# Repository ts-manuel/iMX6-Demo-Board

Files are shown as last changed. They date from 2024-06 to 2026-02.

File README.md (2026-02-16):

# i.MX6 Demo Board
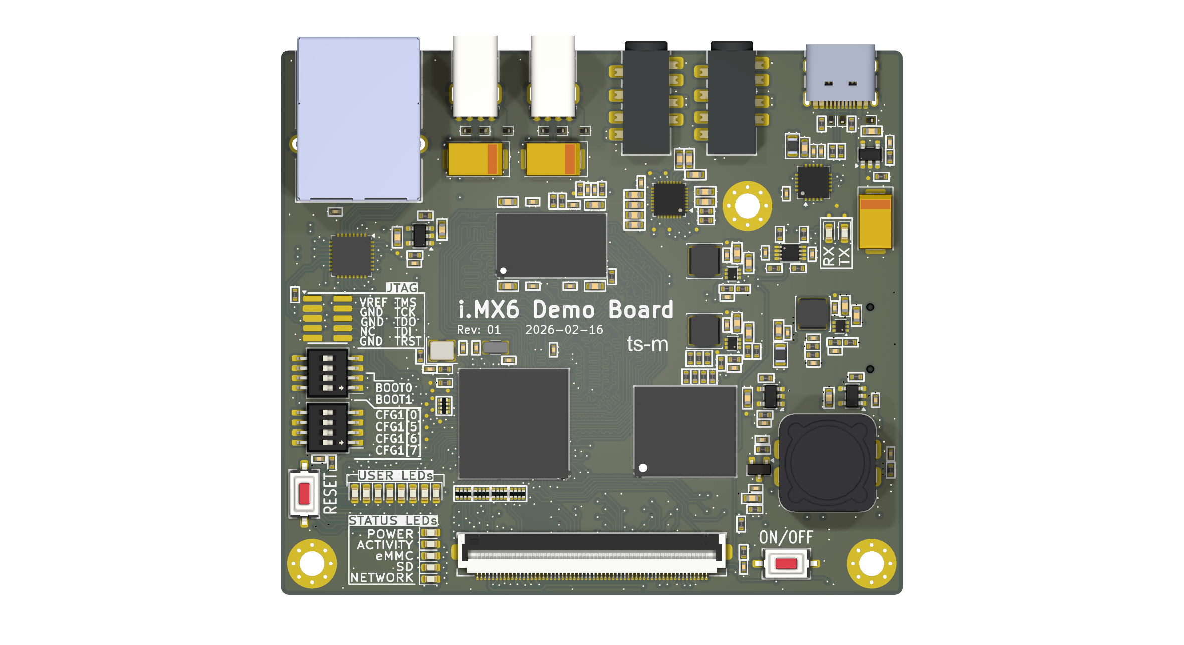
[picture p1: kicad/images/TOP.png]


<!-- TABLE OF CONTENTS -->
<details open="open">
  <summary>Table of Contents</summary>
  <ol>
    <li><a href="#about-the-project">About The Project</a></li>
    <li><a href="#hardware-specifications">Hardware Specifications</a></li>
    <li><a href="#software">Software</a></li>
    <li><a href="#schematic">Schematic</a></li>
  </ol>
</details>

<!-- ABOUT THE PROJECT -->
## About The Project
This repository contains the design files and documentation for a custom-built Linux demo board based on the NXP i.MX6ULL (900 MHz ARM Cortex-A7). The purpose of this project isn't to solve a specific problem or build a commercial product. This is a dedicated learning platform designed to bridge the gap between simple micro-controllers and complex application processors. While micro-controllers (like STM32 or ESP32) are great for real-time tasks, application processors are better suited for "heavy lifting" and high-level software stacks. Checkout the full schematic [schematic](./kicad/schematic/iMX6%20Demo%20Board.pdf) and the <a href="https://htmlpreview.github.io/?https://github.com/ts-manuel/iMX6-Demo-Board/blob/main/kicad/bom/ibom.html" target="_blank">Interactive BOM</a>.

### Hardware Specifications
- **System**
    - CPU: NXP i.MX6ULL @ 900 MHz (ARM Cortex-A7)
    - RAM: 512 MB DDR3
- **Storage:**
    - 4 GB eMMC (On-board)
    - 32 MB NOR Quad SPI
    - Micro SD-Card Slot
- **Connectivity:**
    - 1x 100Mb Ethernet
    - 2x USB 2.0 Host (Type A)
    - 1x USB 2.0 Device (Type C)
    - 2x Audio Jacks 3.5 mm (WM8904 Codec)
- **UI & Indicators:**
    - 24-bit LCD Interface
    - 8x User LEDs + 5x Status LEDs

<!-- SOFTWARE -->
## Software
The current goal is to compile a basic Linux image using the Yocto Project to exercise and validate every hardware feature on the board (Ethernet, USB, Display, and GPIO).

**Status: In Progress**. Development of the custom meta-layer and bitbake recipes is currently underway.

<!-- SCHEMATIC -->
## Schematic
Checkout the full [schematic](./kicad/schematic/iMX6%20Demo%20Board.pdf) in PDF.

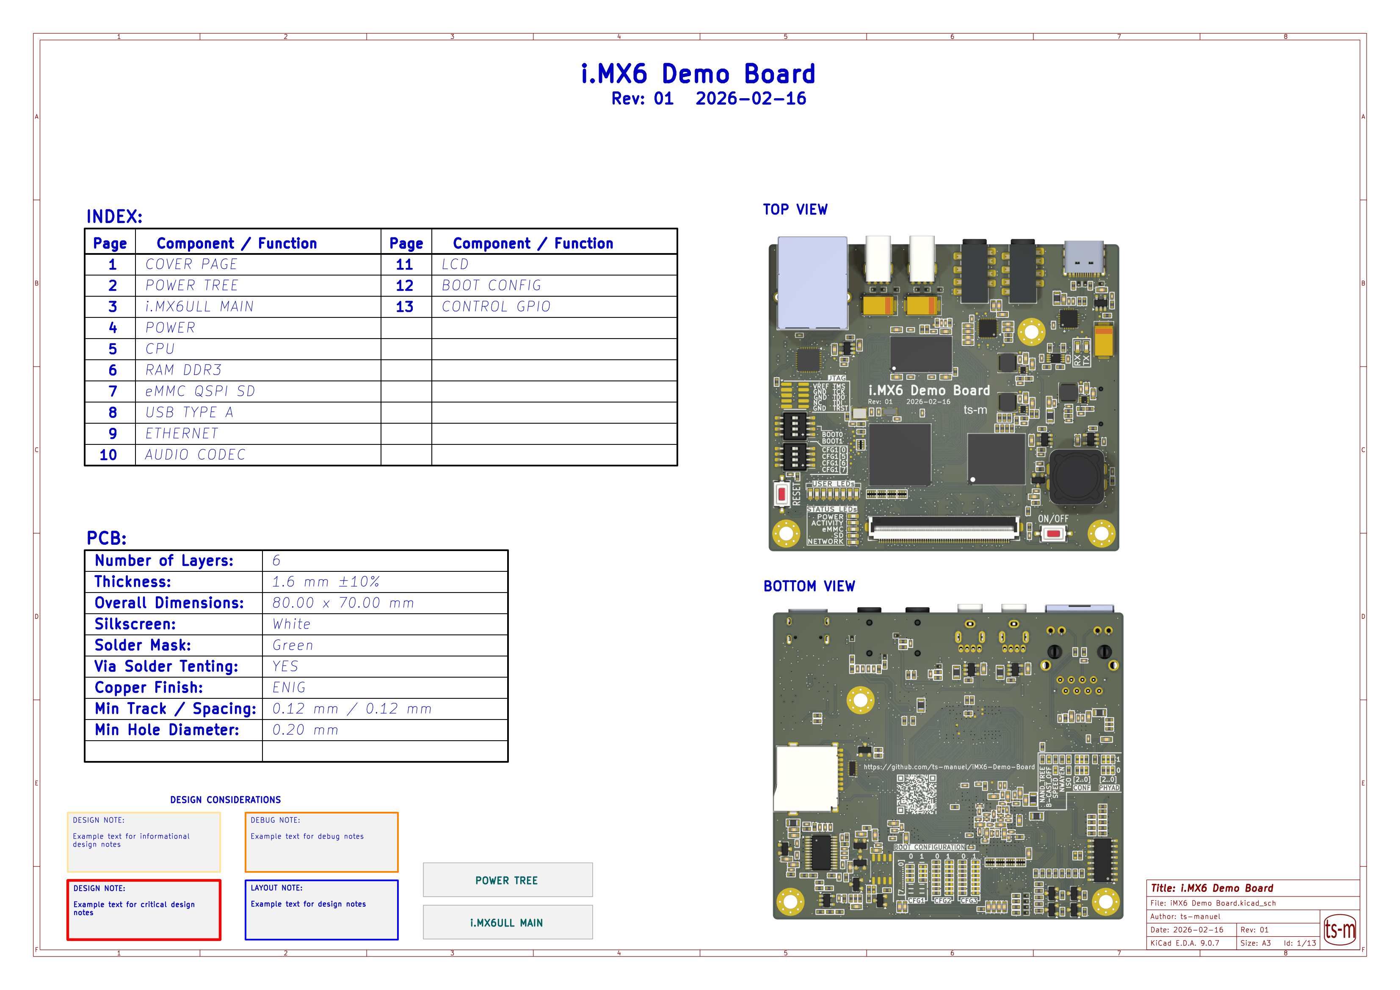
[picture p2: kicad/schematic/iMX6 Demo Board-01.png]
iMX6 Demo Board-01.png


### POWER TREE
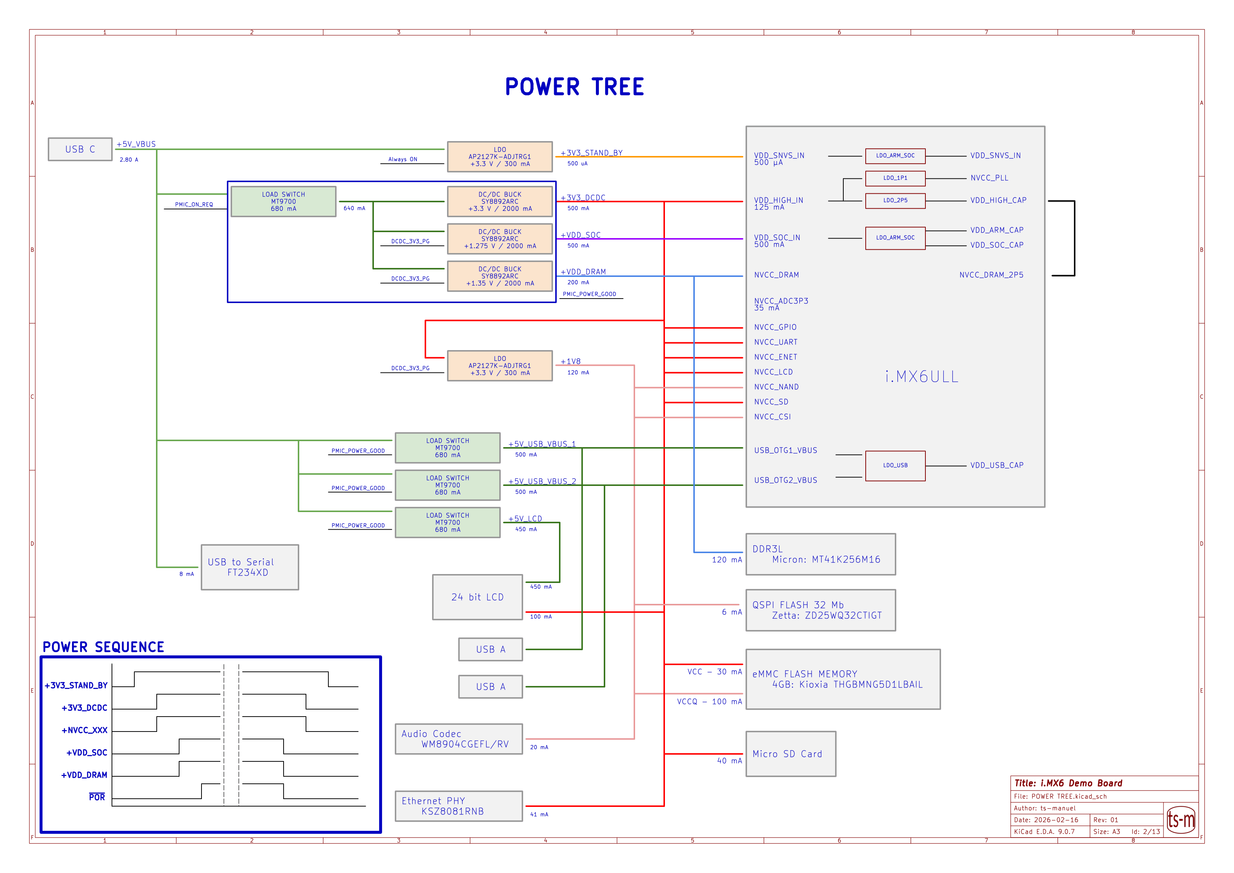
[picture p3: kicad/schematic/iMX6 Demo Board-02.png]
iMX6 Demo Board-02.png


### BLOCK DIAGRAM
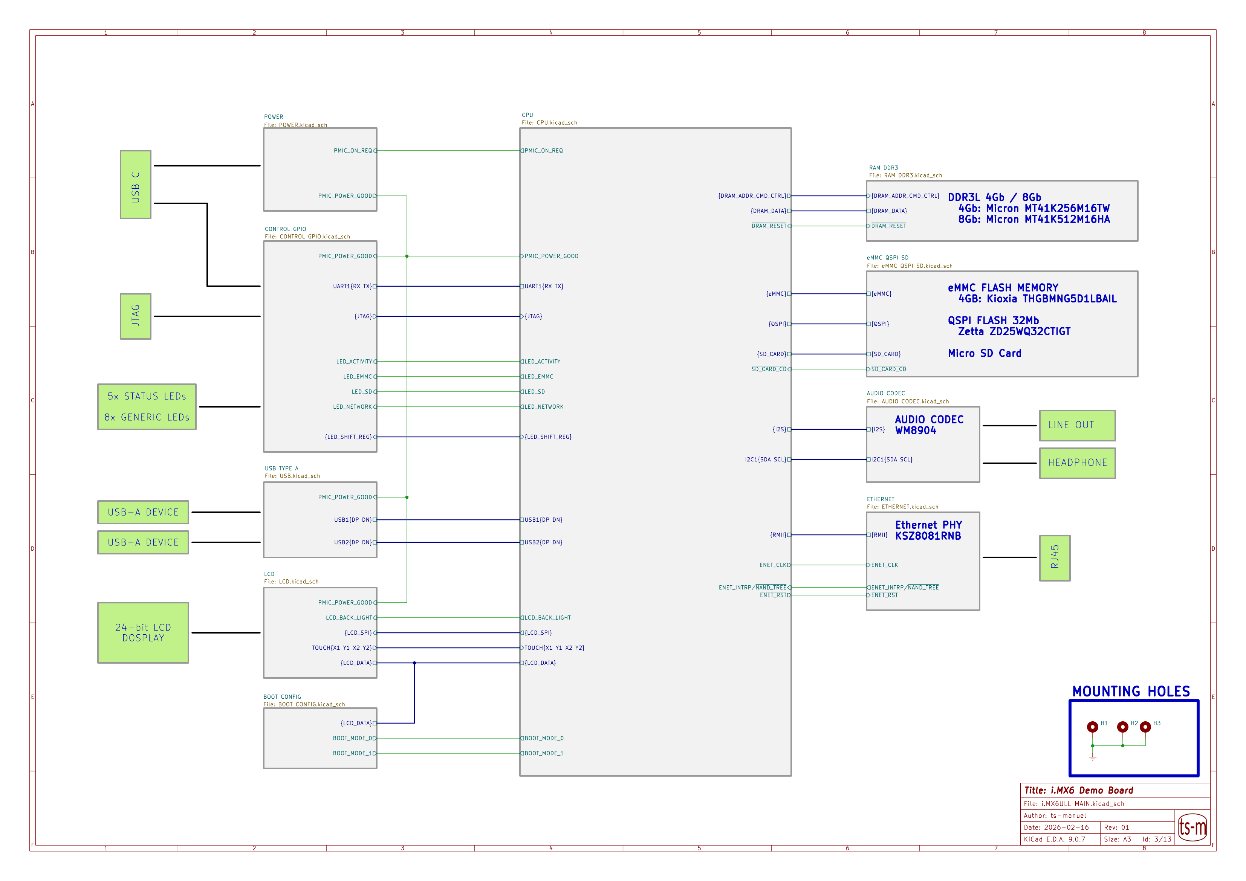
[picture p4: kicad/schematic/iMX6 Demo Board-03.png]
iMX6 Demo Board-03.png


### POWER
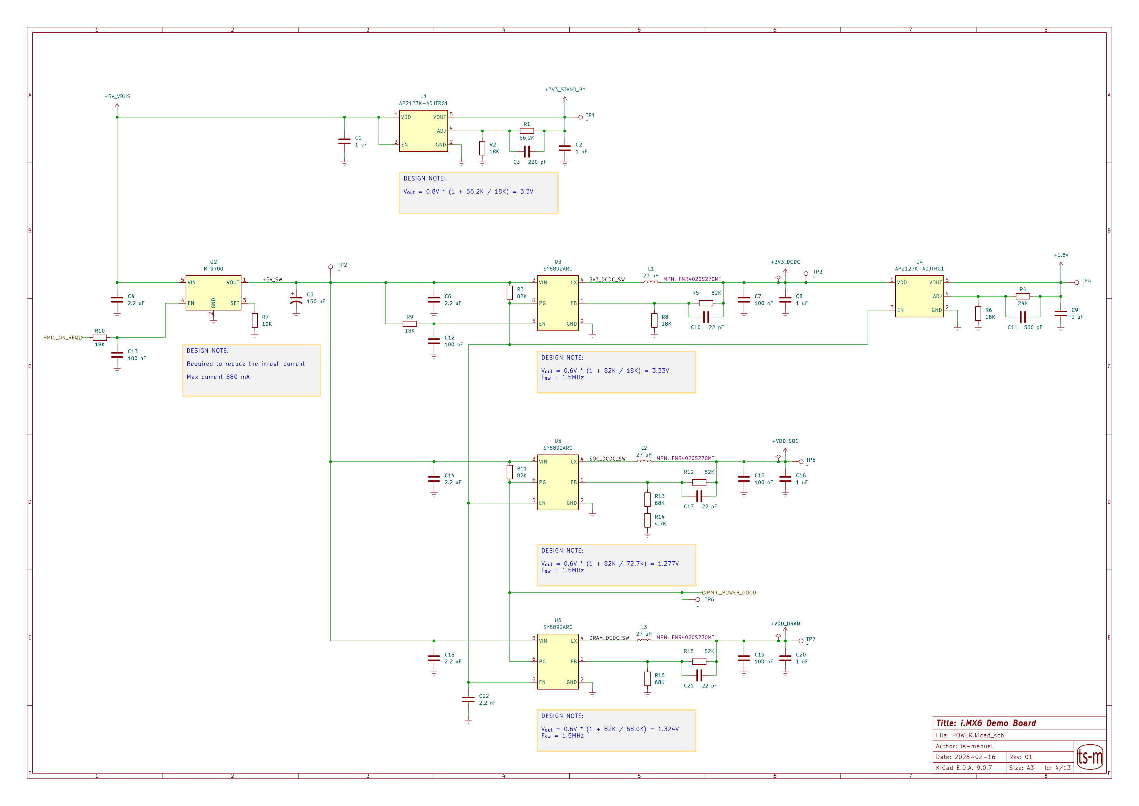
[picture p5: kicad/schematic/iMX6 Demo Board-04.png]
iMX6 Demo Board-04.png


### CPU
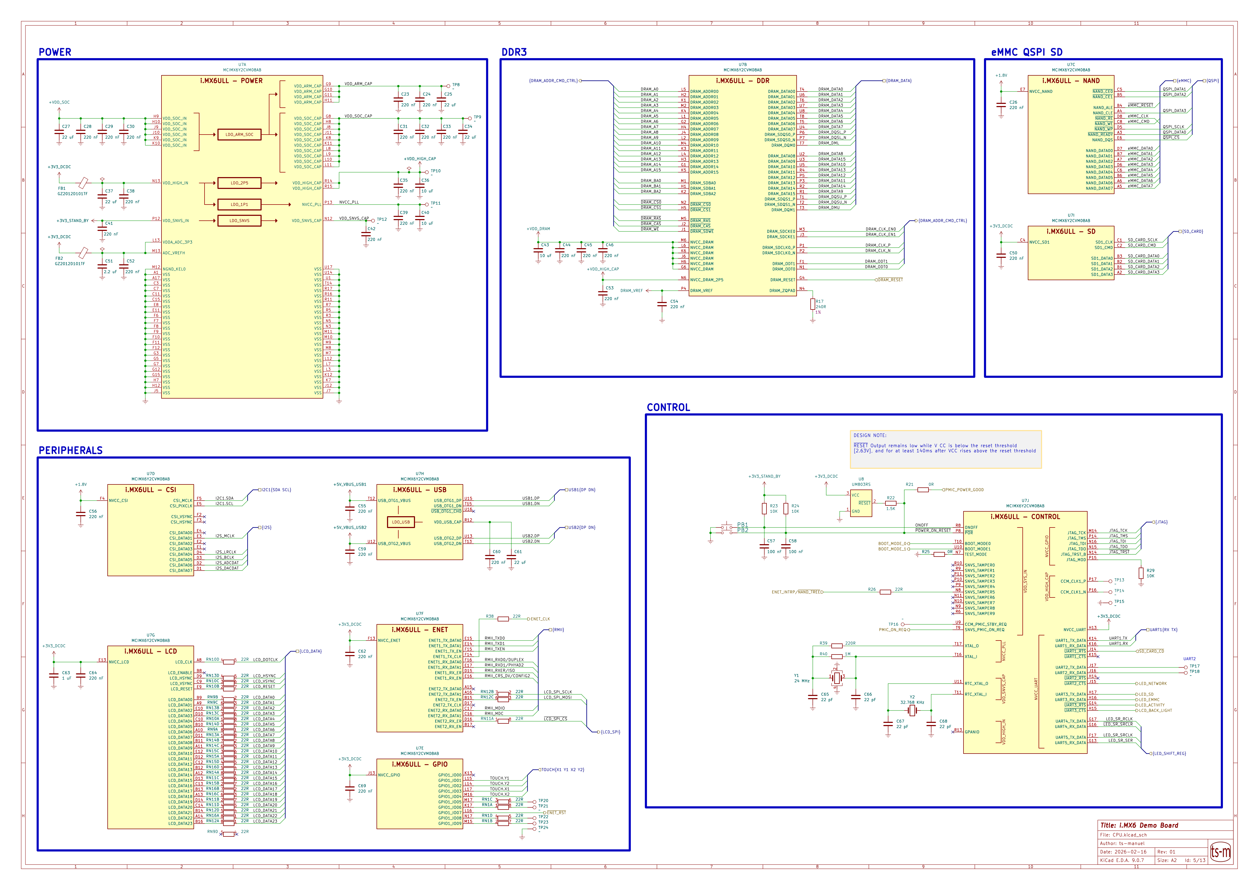
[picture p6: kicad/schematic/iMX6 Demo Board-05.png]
iMX6 Demo Board-05.png


### RAM DDR3
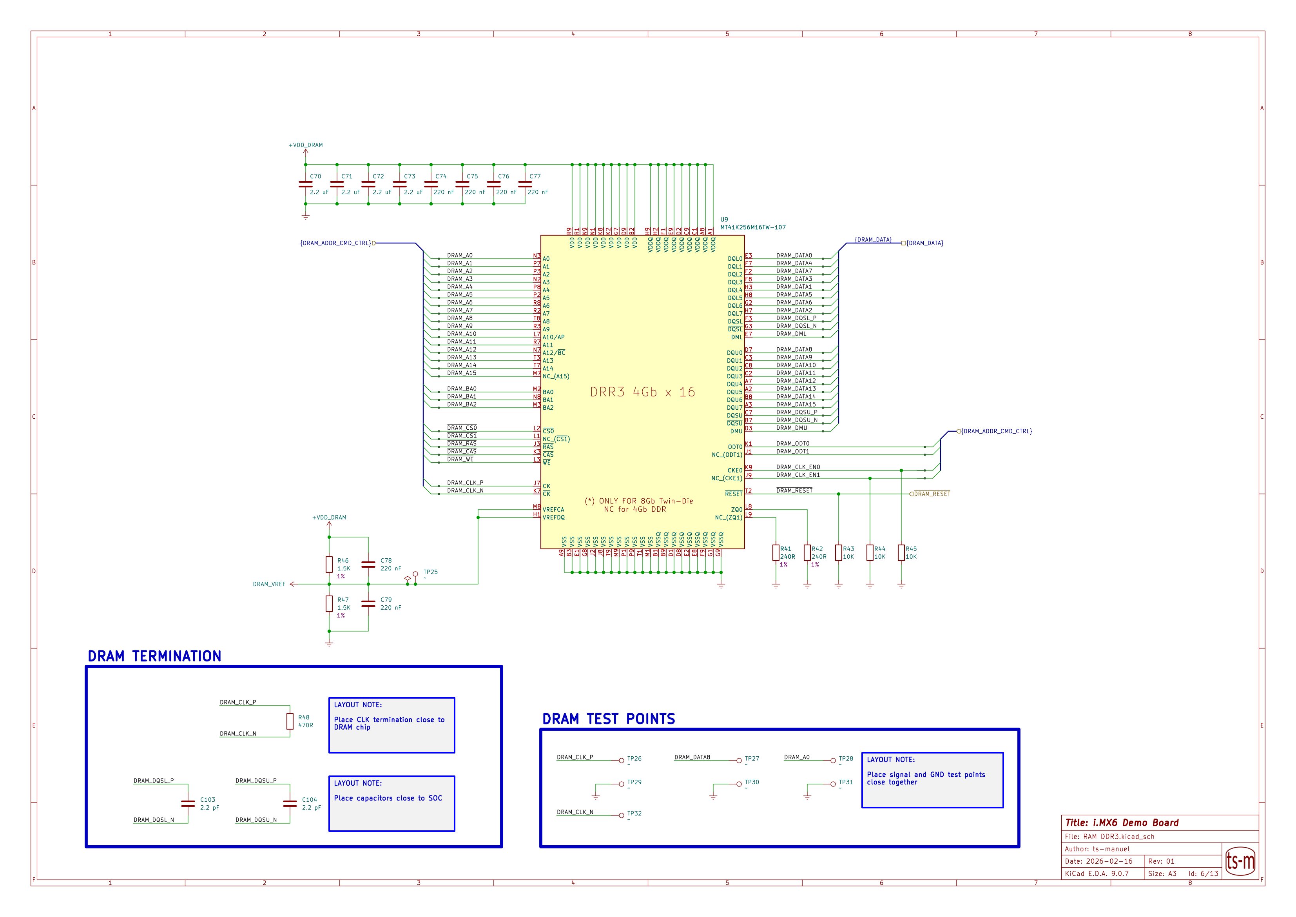
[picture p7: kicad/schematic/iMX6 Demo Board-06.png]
iMX6 Demo Board-06.png


### eMMC QSPI SD
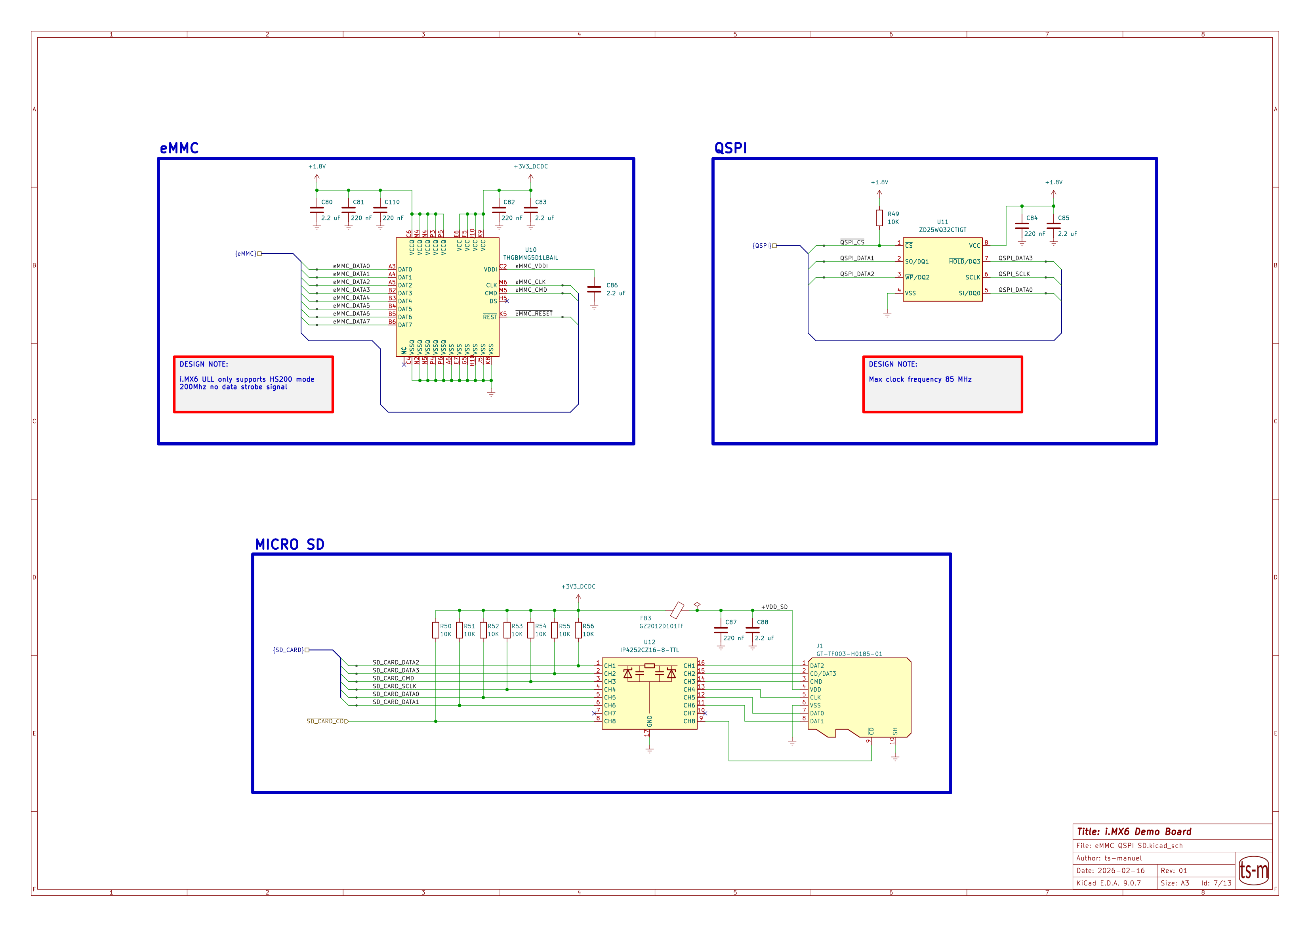
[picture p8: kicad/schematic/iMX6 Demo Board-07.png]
iMX6 Demo Board-07.png


### USB TYPE A
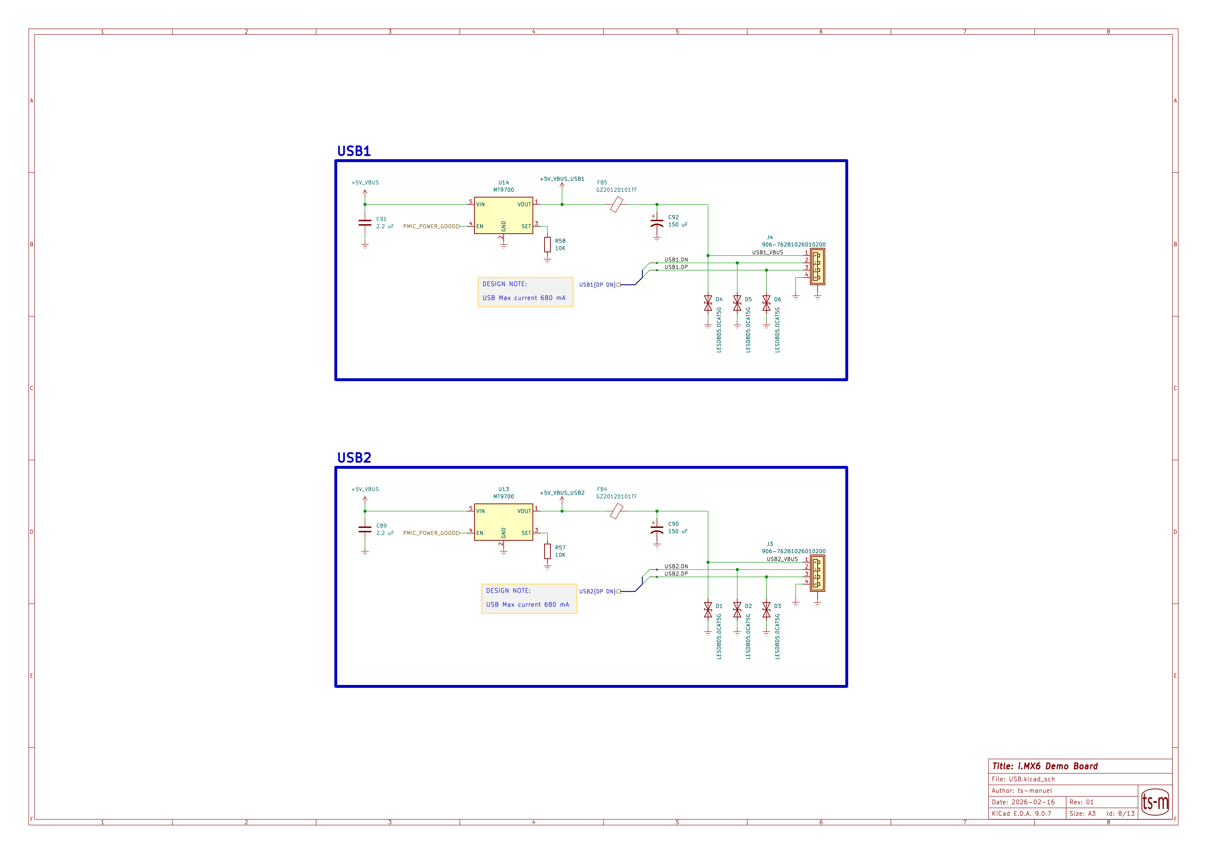
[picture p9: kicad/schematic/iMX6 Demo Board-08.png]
iMX6 Demo Board-08.png


### ETHERNET
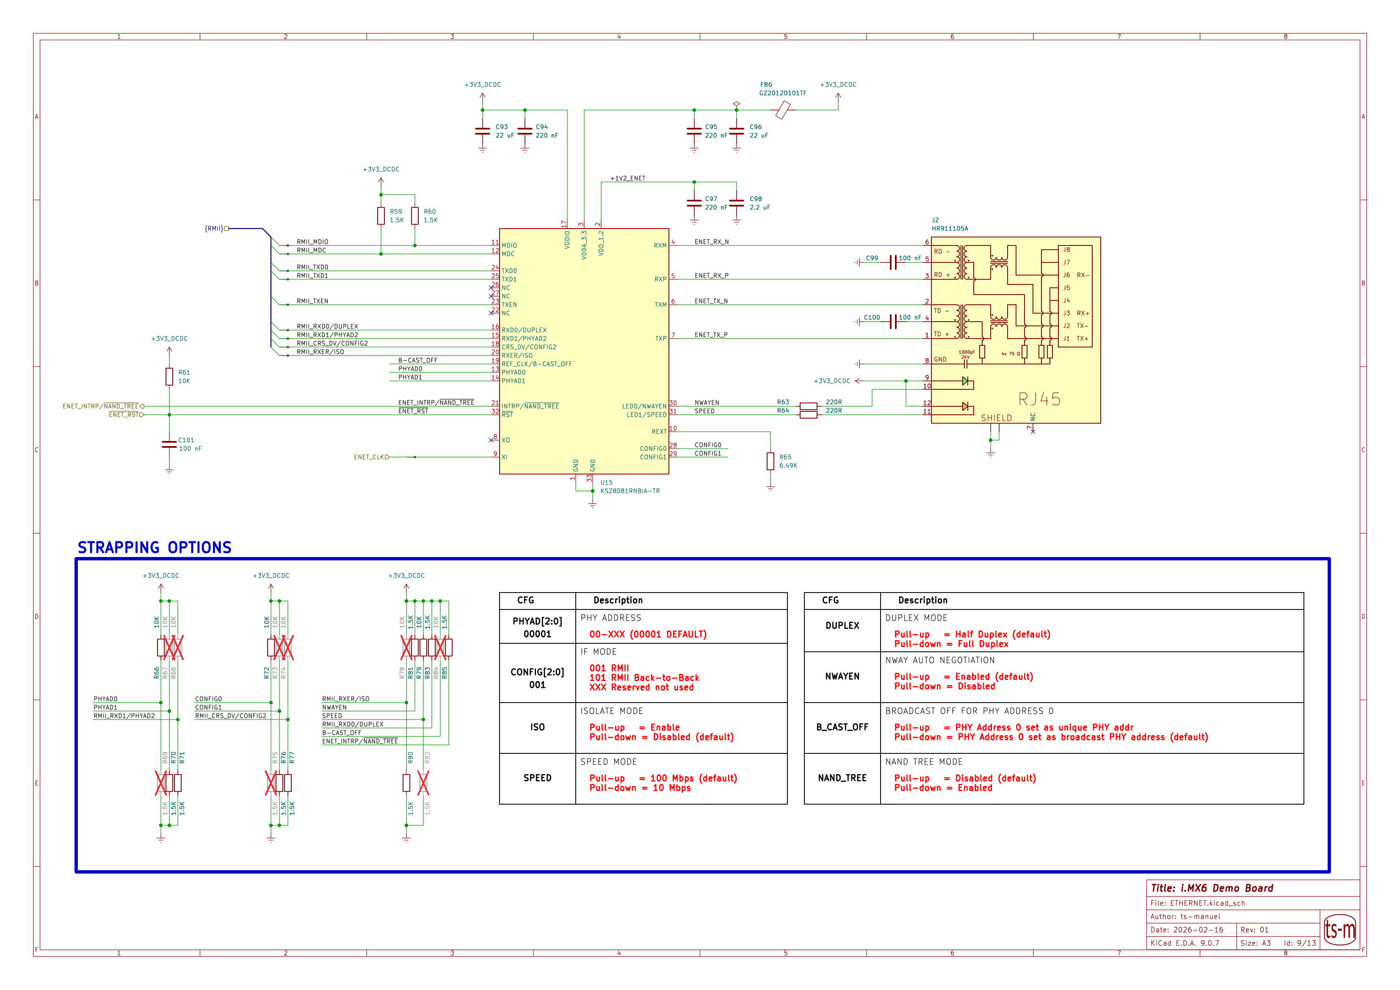
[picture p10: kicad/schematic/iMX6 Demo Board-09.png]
iMX6 Demo Board-09.png


### AUDIO CODEC
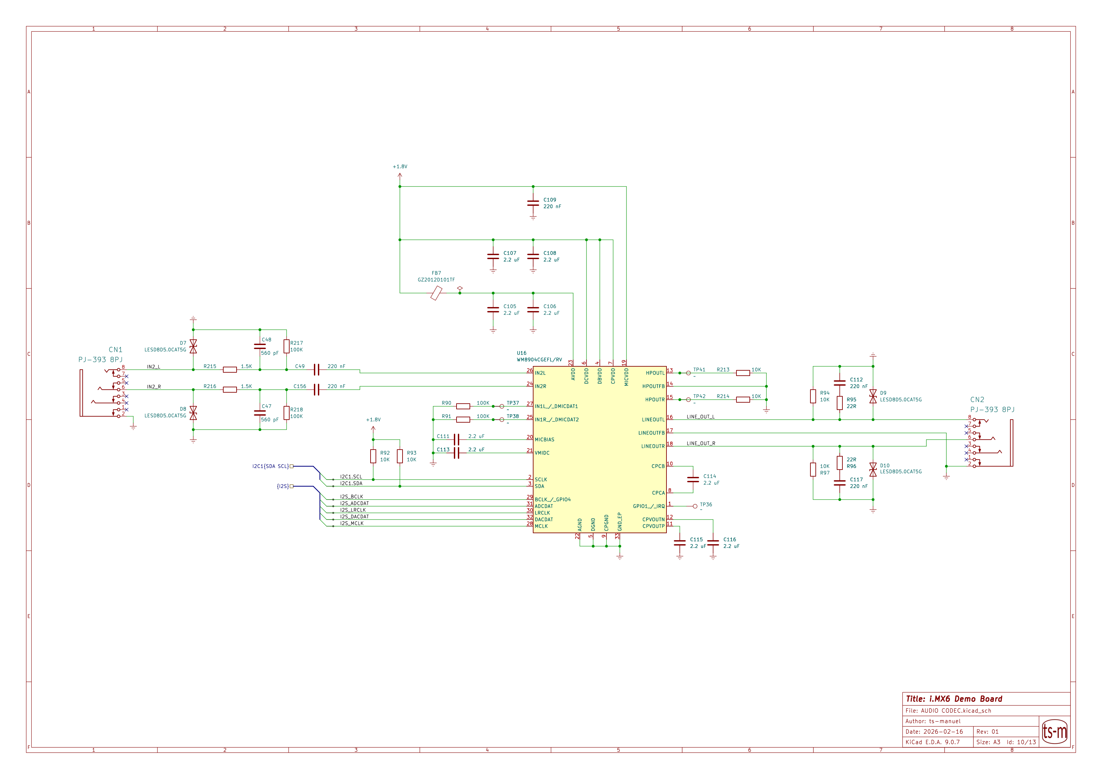
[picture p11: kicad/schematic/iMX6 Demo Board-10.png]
iMX6 Demo Board-10.png


### LCD
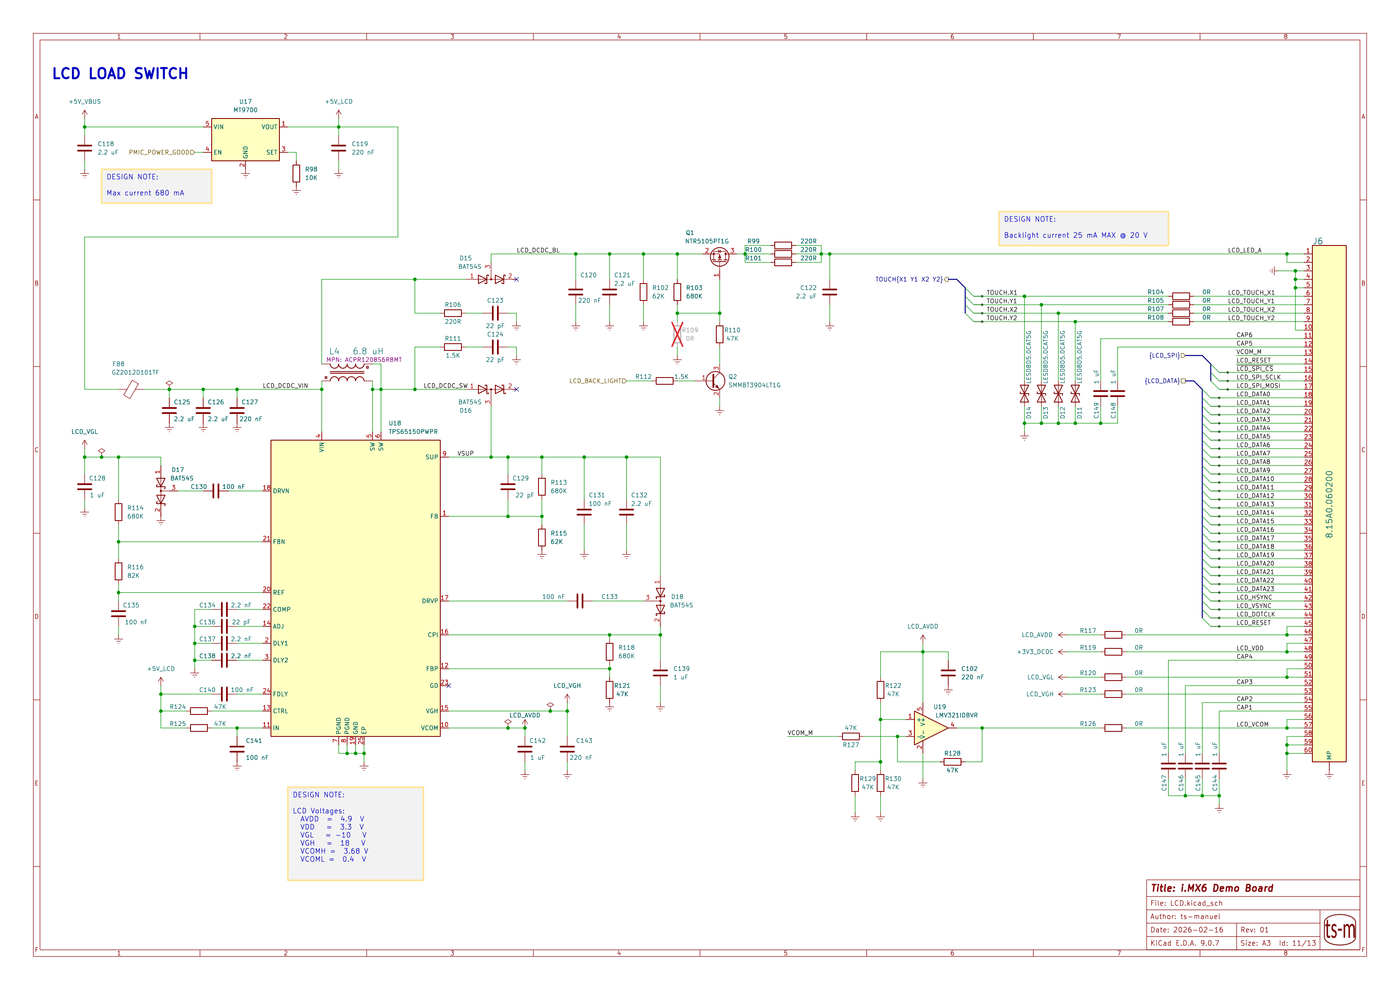
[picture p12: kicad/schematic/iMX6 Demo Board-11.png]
iMX6 Demo Board-11.png


### BOOT CONFIG
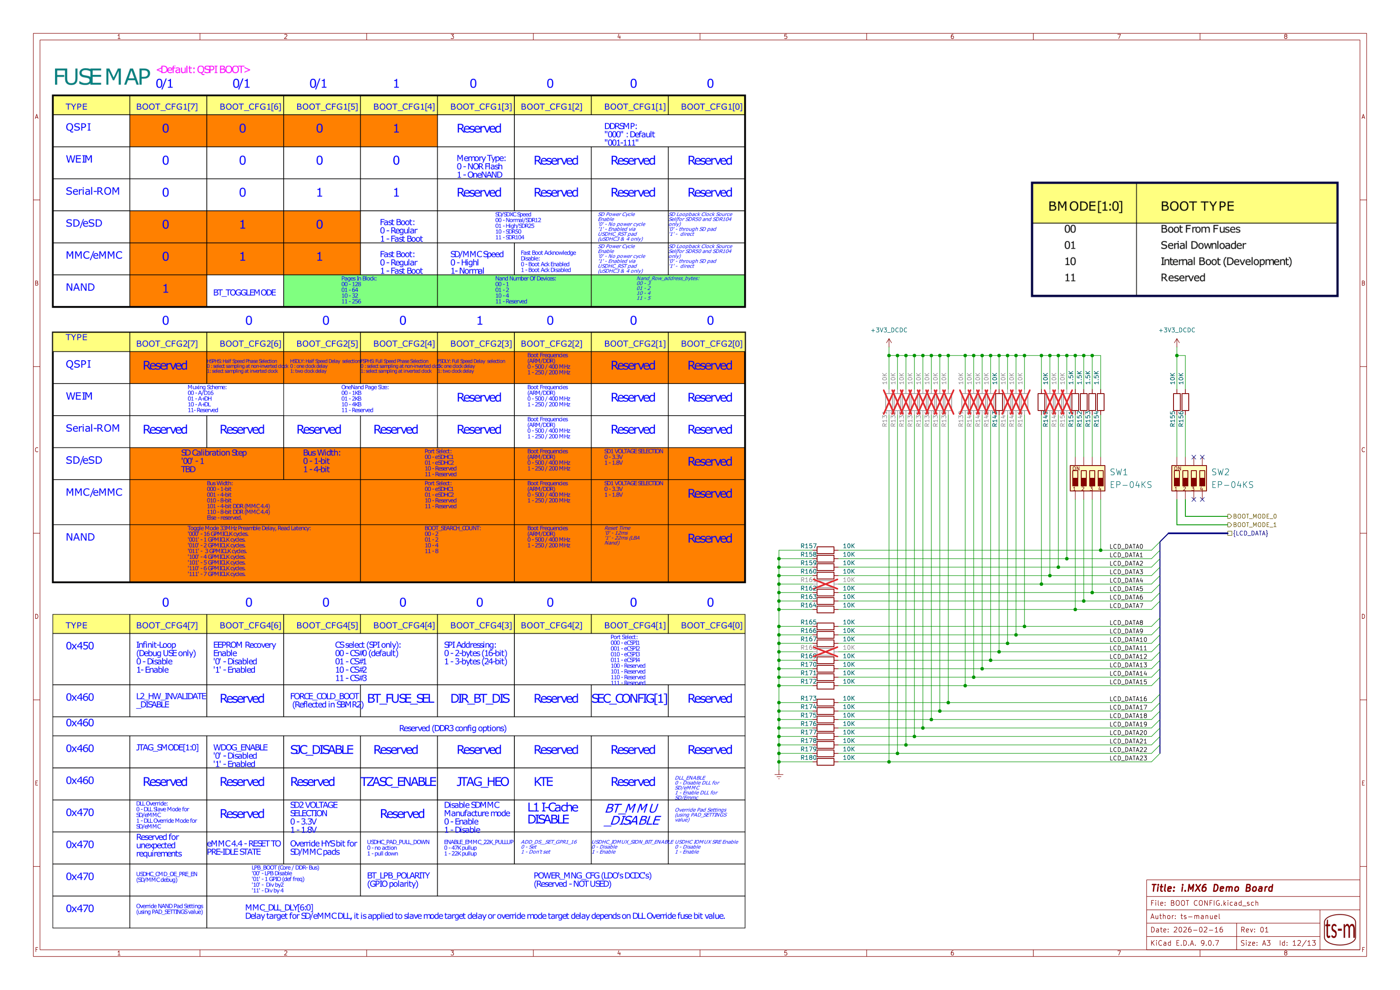
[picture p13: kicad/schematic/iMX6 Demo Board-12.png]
iMX6 Demo Board-12.png


### CONTROL GPIO
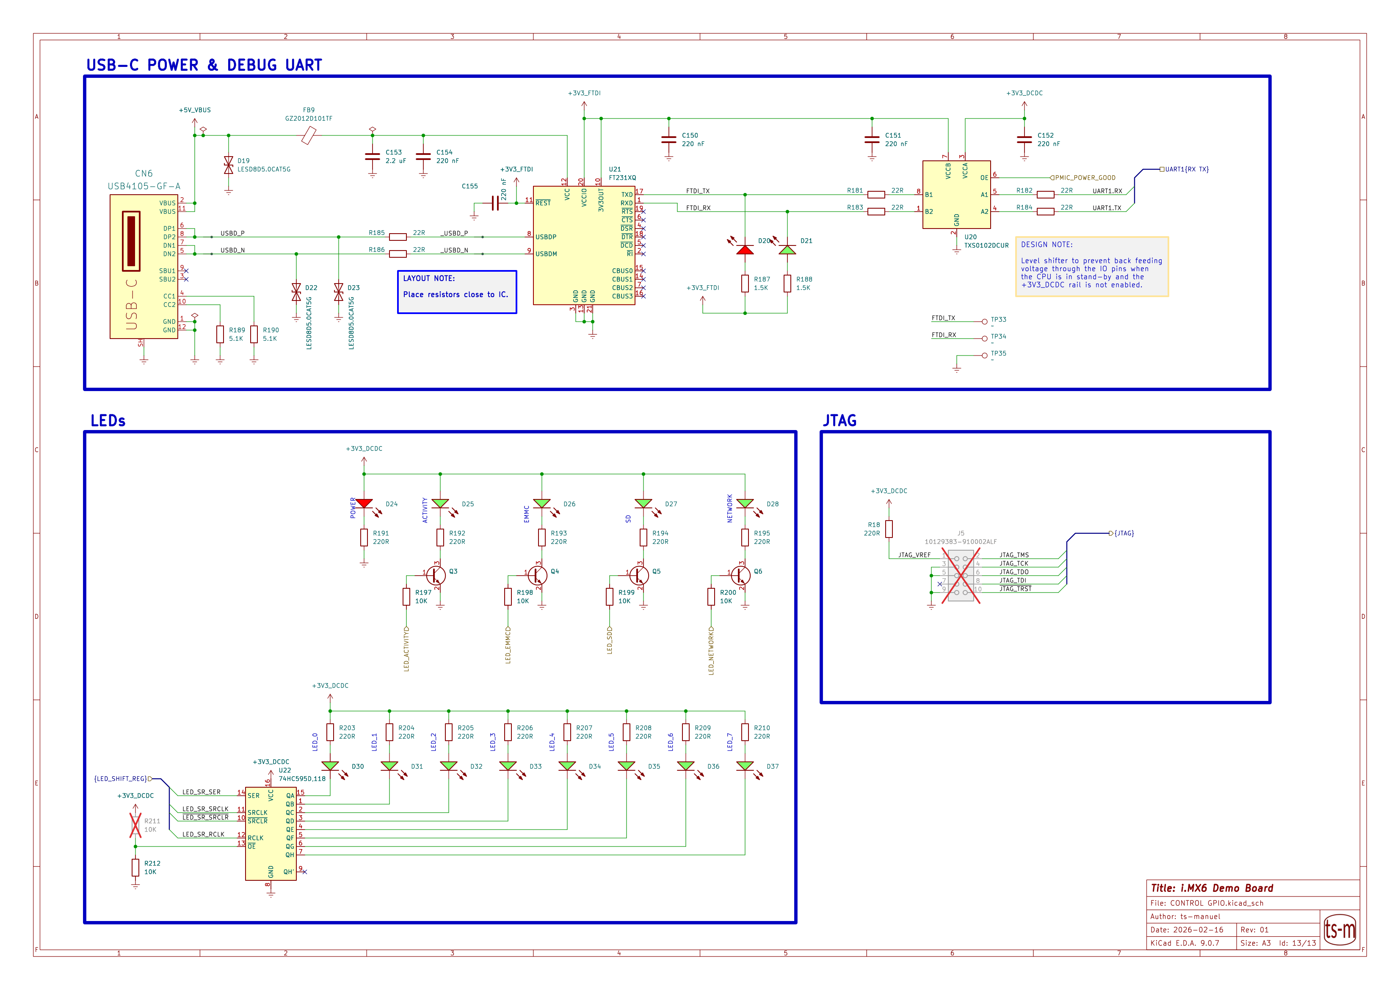
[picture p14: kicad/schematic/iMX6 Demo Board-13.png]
iMX6 Demo Board-13.png


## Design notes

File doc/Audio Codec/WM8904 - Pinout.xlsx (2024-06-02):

NAME | WLCSP 6x6 | QFN-32 | TYPE | DESCRIPTION
GPIO1 / IRQ | C5 | 1 | Digital Input / Output | GPIO1 / Interrupt
SCLK | B6 | 2 | Digital Input | Control interface clock input
IN3L | C3 | n/a | Analogue Input | Left channel input 3
SDA | D4 | 3 | Digital Input / Output | Control interface data input / output
DBVDD | C6 | 4 | Supply | Digital buffer supply (powers audio interface and control interface)
IN3R | C2 | n/a | Analogue Input | Right channel input 3
DGND | D6 | 5 | Supply | Digital ground (return path for DCVDD and DBVDD)
DCVDD | D5 | 6 | Supply | Digital core supply
CPVDD | E6 | 7 | Supply | Charge pump power supply
CPCA | E5 | 8 | Analogue Output | Charge pump flyback capacitor pin
CPGND | F6 | 9 | Supply | Charge pump ground
CPCB | F5 | 10 | Analogue Output | Charge pump flyback capacitor pin
CPVOUTP | E4 | 11 | Analogue Output | Charge pump positive supply decoupling (powers HPOUTL/R, LINEOUTL/R)
CPVOUTN | F4 | 12 | Analogue Output | Charge pump negative supply decoupling (powers HPOUTL/R, LINEOUTL/R)
HPOUTL | E3 | 13 | Analogue Output | Left headphone output (line or headphone output)
HPOUTFB | F3 | 14 | Analogue Input | Headphone output ground loop noise rejection feedback
HPOUTR | E2 | 15 | Analogue Output | Right headphone output (line or headphone output)
LINEOUTL | F2 | 16 | Analogue Output | Left line output 1 (line output)
LINEOUTFB | D2 | 17 | Analogue Input | Line output ground loop noise rejection feedback
LINEOUTR | F1 | 18 | Analogue Output | Right line output 1 (line output)
MICVDD | E1 | 19 | Supply | Microphone bias amp supply
MICBIAS | D1 | 20 | Analogue Output | Microphone bias
VMIDC | D3 | 21 |  | Midrail voltage decoupling capacitor
AGND | C1 | 22 | Supply | Analogue power return
AVDD | B1 | 23 | Supply | Analogue power supply (powers analogue inputs, reference, ADC, DAC)
IN2R | B2 | 24 | Analogue Input | Right channel input 2
IN1R / DMICDAT2 | A1 | 25 | Analogue / Digital Input | Right channel input 1 / Digital microphone data input 2
IN2L | A2 | 26 | Analogue Input | Left channel input 2
IN1L / DMICDAT1 | B3 | 27 | Analogue / Digital Input | Left channel input 1 / Digital microphone data input 1
MCLK | A4 | 28 | Digital Input | Master clock for CODEC
BCLK / GPIO4 | C4 | 29 | Digital Input / Output | Audio interface bit clock / GPIO4
LRCLK | A5 | 30 | Digital Input / Output | Audio interface left / right clock (common for ADC and DAC)
ADCDAT | B5 | 31 | Digital Output | ADC digital audio data
DACDAT | A6 | 32 | Digital Input | DAC digital audio data
GPIO2 | B4 | n/a | Digital Input / Output | GPIO2
GPIO3 | A3 | n/a | Digital Input / Output | GPIO3
GND_PADDLE | n/a | 33 |  | Die Paddle

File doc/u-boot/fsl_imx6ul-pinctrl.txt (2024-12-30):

* Freescale i.MX6 UltraLite IOMUX Controller

Please refer to fsl,imx-pinctrl.txt in this directory for common binding part
and usage.

Required properties:
- compatible: "fsl,imx6ul-iomuxc" for main IOMUX controller or
  "fsl,imx6ull-iomuxc-snvs" for i.MX 6ULL's SNVS IOMUX controller.
- fsl,pins: each entry consists of 6 integers and represents the mux and config
  setting for one pin.  The first 5 integers <mux_reg conf_reg input_reg mux_val
  input_val> are specified using a PIN_FUNC_ID macro, which can be found in
  imx6ul-pinfunc.h under device tree source folder.  The last integer CONFIG is
  the pad setting value like pull-up on this pin.  Please refer to i.MX6 UltraLite
  Reference Manual for detailed CONFIG settings.

CONFIG bits definition:
PAD_CTL_HYS                     (1 << 16)
PAD_CTL_PUS_100K_DOWN           (0 << 14)
PAD_CTL_PUS_47K_UP              (1 << 14)
PAD_CTL_PUS_100K_UP             (2 << 14)
PAD_CTL_PUS_22K_UP              (3 << 14)
PAD_CTL_PUE                     (1 << 13)
PAD_CTL_PKE                     (1 << 12)
PAD_CTL_ODE                     (1 << 11)
PAD_CTL_SPEED_LOW               (0 << 6)
PAD_CTL_SPEED_MED               (1 << 6)
PAD_CTL_SPEED_HIGH              (3 << 6)
PAD_CTL_DSE_DISABLE             (0 << 3)
PAD_CTL_DSE_260ohm              (1 << 3)
PAD_CTL_DSE_130ohm              (2 << 3)
PAD_CTL_DSE_87ohm               (3 << 3)
PAD_CTL_DSE_65ohm               (4 << 3)
PAD_CTL_DSE_52ohm               (5 << 3)
PAD_CTL_DSE_43ohm               (6 << 3)
PAD_CTL_DSE_37ohm               (7 << 3)
PAD_CTL_SRE_FAST                (1 << 0)
PAD_CTL_SRE_SLOW                (0 << 0)

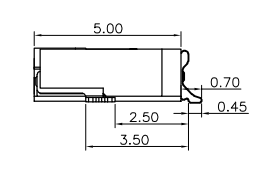
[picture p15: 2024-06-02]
doc/LCD/Lato.PNG

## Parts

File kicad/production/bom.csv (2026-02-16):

Designator | Footprint | Quantity | Value | LCSC Part #
C1, C128, C139, C142, C144, C145, C146, C147, C148, C149, C16, C2, C20, C63, C8, C9 | CAP-0603 | 16 | 1 uF | C90540
C10, C123, C124, C129, C136, C17, C21, C65, C66, C67, C68 | CAP-0402 | 11 | 22 pF | C5137569
C100, C101, C12, C13, C130, C131, C133, C135, C140, C141, C15, C19, C57, C58, C7, C99 | CAP-0402 | 16 | 100 nF | C77020
C102, C109, C110, C112, C117, C119, C120, C127, C143, C150, C151, C152, C154, C155, C156, C23, C24, C26, C28, C29, C30, C31, C32, C33, C35, C38, C39, C41, C42, C44, C45, C46, C49, C50, C52, C53, C54, C55, C56, C59, C60, C62, C64, C69, C74, C75, C76, C77, C78, C79, C81, C82, C84, C87, C94, C95, C97 | CAP-0402 | 57 | 220 nF | C192432
C103, C104 | CAP-0402 | 2 | 2.2 pF | C880648
C105, C106, C107, C108, C111, C113, C114, C115, C116, C118, C121, C122, C125, C126, C132, C14, C153, C18, C4, C51, C6, C70, C71, C72, C73, C80, C83, C85, C86, C88, C89, C91, C98 | CAP-0603 | 33 | 2.2 uF | C23630
C11, C47, C48 | CAP-0402 | 3 | 560 pF | C107008
C134, C137, C138, C22 | CAP-0402 | 4 | 2.2 nF | C106861
C25, C27, C34, C37, C61, C93, C96 | CAP-0603 | 7 | 22 uF | C93926
C3 | CAP-0402 | 1 | 220 pF | C107001
C36, C40, C43 | CAP-0603 | 3 | 10 uF | C19702
C5, C90, C92 | CP_EIA-7343-31_Kemet-D | 3 | 150 uF | C127980
CN1, CN2 | Jack_SMD_3.5mm_PJ-393-8PJ | 2 | PJ-393 8PJ | C668609
CN6 | USB-TYPE-C-12P | 1 | USB4105-GF-A | C2765186
D1, D10, D11, D12, D13, D14, D19, D2, D22, D23, D3, D4, D5, D6, D7, D8, D9 | D_SOD-882 | 17 | LESD8D5.0CAT5G | C172411
D15, D16, D17, D18 | SOT-23 | 4 | BAT54S | C7420333
D20, D24 | 0603 | 2 | 150060RS75003 | C2286
D21, D25, D26, D27, D28, D30, D31, D32, D33, D34, D35, D36, D37 | 0603 | 13 | 150060VS75000 | C965805
FB1, FB2, FB3, FB4, FB5, FB6, FB7, FB8, FB9 | FB-0805 | 9 | GZ2012D101TF | C1015
J1 | MicroSD_G-Switch _GT-TF003-H0185-01 | 1 | GT-TF003-H0185-01 | C5155563
J2 | RJ45_THT-HR911105A | 1 | HR911105A | C12074
J3, J4 | USB-TypeA-906-762B1026D10200 | 2 | 906-762B1026D10200 | C2763240
J6 | CN-FPC-60P_0.5mm_Bot_8.15A0.060200 | 1 | 8.15A0.060200 | C20626046
L1, L2, L3 | IND-SMD-FNR4020S | 3 | 27 uH | C167839
L4 | IND-SMD-ACPR1208S | 1 | 6.8 uH | C2846215
PB1, PB2 | BTN_SMD_PTS636-SK25-SMTR-LFS | 2 | PTS636 SK25 SMTR LFS | C2689642
Q1 | SOT-23 | 1 | NTR5105PT1G | C328099
Q2, Q3, Q4, Q5, Q6 | SOT-23 | 5 | SMMBT3904LT1G | C49580
R1 | RES-0402 | 1 | 56.2K | C705626
R10, R2, R6, R8, R9 | RES-0402 | 5 | 18K | C25762
R100, R101, R106, R18, R191, R192, R193, R194, R195, R203, R204, R205, R206, R207, R208, R209, R210, R39, R63, R64, R99 | RES-0402 | 21 | 220R | C25091
R102, R115 | RES-0402 | 2 | 62K | C37825
R103, R113, R114, R118 | RES-0402 | 4 | 680K | C163456
R104, R105, R107, R108, R117, R119, R120, R123, R126, R21, R25 | RES-0402 | 11 | 0R | C17168
R11, R116, R12, R15, R3, R5 | RES-0402 | 6 | 82K | C4142
R110, R121, R122, R124, R125, R127, R128, R129, R130 | RES-0402 | 9 | 47K | C25792
R111, R112, R151, R152, R153, R154, R187, R188, R215, R216, R22, R46, R47, R59, R60, R70, R71, R76, R77, R80, R81, R83, R85 | RES-0402 | 23 | 1.5K | C25867
R13, R16 | RES-0402 | 2 | 68K | C36871
R14 | RES-0402 | 1 | 4.7K | C105871
R143, R147, R155, R156, R157, R158, R159, R160, R162, R163, R164, R165, R166, R167, R169, R170, R171, R172, R173, R174, R175, R176, R177, R178, R179, R180, R197, R198, R199, R200, R212, R213, R214, R23, R24, R29, R43, R44, R45, R49, R50, R51, R52, R53, R54, R55, R56, R57, R58, R61, R66, R7, R72, R79, R92, R93, R94, R97, R98 | RES-0402 | 59 | 10K | C25744
R17, R41, R42 | RES-0402 | 3 | 240R | C25094
R181, R182, R183, R184, R185, R186, R26, R38, R95, R96 | RES-0402 | 10 | 22R | C25092
R189, R190 | RES-0402 | 2 | 5.1K | C25905
R217, R218, R90, R91 | RES-0402 | 4 | 100K | C25741
R4 | RES-0402 | 1 | 24K | C409902
R40 | RES-0402 | 1 | 1M | C409676
R48 | RES-0402 | 1 | 470R | C25117
R65 | RES-0402 | 1 | 6.49K | C25916
RN1, RN10, RN11, RN12, RN13, RN14, RN15, RN16, RN9 | R_Array_Convex_4x0402 | 9 | 22R | C25499
SW1, SW2 | SW_DIP_SPSTx04_Slide_Copal_CHS-04B_W7.62mm_P1.27mm | 2 | EP-04KS | C129088
U1, U4 | SOT-23-5 | 2 | AP2127K-ADJTRG1 | C96343
U10 | BGA-153_13.0x11.5mm_Ball0.30mm_Pad0.25mm | 1 | THGBMNG5D1LBAIL | C391255
U11 | SOP-8_3.9x4.9mm_P1.27mm | 1 | ZD25WQ32CTIGT | C5290169
U12 | Nexperia_HUSON-16_USON-16-1EP_1.35x3.3mm_P0.4mm_EP0.4x2.8mm | 1 | IP4252CZ16-8-TTL | C458218
U13, U14, U17, U2 | SOT-23-5 | 4 | MT9700 | C89855
U15 | QFN-32-1EP_5x5mm_P0.5mm_EP3.1x3.1mm | 1 | KSZ8081RNBIA-TR | C100018
U16 | QFN-32-1EP_4x4mm_P0.4mm_EP2.65x2.65mm | 1 | WM8904CGEFL/RV | C323845
U18 | HTSSOP-24-1EP_4.4x7.8mm_P0.65mm_EP3.4x7.8mm_Mask2.4x4.68mm | 1 | TPS65150PWPR | C140349
U19 | SOT-23-5 | 1 | LMV321IDBVR | C7972
U20 | VSSOP-8_2.3x2mm_P0.5mm | 1 | TXS0102DCUR | C53434
U21 | QFN-20-1EP_4x4mm_P0.5mm_EP2.5x2.5mm | 1 | FT231XQ | C132159
U22 | SO-16_3.9x9.9mm_P1.27mm | 1 | 74HC595D,118 | C5947
U3, U5, U6 | SOT-563 | 3 | SY8892ARC | C3151908
U7 | BGA-289P08L17x17_14.0x14.0mm_Ball0.35mm_Pad0.30mm | 1 | MCIMX6Y2CVM08AB | C414042
U8 | SOT-23 | 1 | UM803RS | C620009
U9 | BGA-96P08L9X16_8.0X14.0mm_Ball0.45_Pad0.40mm | 1 | MT41K256M16TW-107 | C367428
Y1 | Crystal_SMD_EuroQuartz_MT-4Pin_3.2x2.5mm | 1 | 24 MHz | C7466181
Y2 | QUARTZ-SC-32S32.768kHz20PPM12.5pF | 1 | 32.768 KHz | C97606

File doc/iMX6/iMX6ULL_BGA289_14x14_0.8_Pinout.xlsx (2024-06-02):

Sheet: Foglio1
POWER
Ball Position | Supply Rail Name
M13 | ADC_VREFH
P4 | DRAM_VREF
R13 | GPANIO
M12 | NGND_KEL0
F4 | NVCC_CSI
G6 | NVCC_DRAM
H6 | NVCC_DRAM
J6 | NVCC_DRAM
K6 | NVCC_DRAM
L6 | NVCC_DRAM
M6 | NVCC_DRAM
N6 | NVCC_DRAM_2P5
F13 | NVCC_ENET
J13 | NVCC_GPIO
E13 | NVCC_LCD
E7 | NVCC_NAND
P13 | NVCC_PLL
C4 | NVCC_SD1
H13 | NVCC_UART
G9 | VDD_ARM_CAP
G10 | VDD_ARM_CAP
G11 | VDD_ARM_CAP
H11 | VDD_ARM_CAP
R14 | VDD_HIGH_CAP
R15 | VDD_HIGH_CAP
N13 | VDD_HIGH_IN
N12 | VDD_SNVS_CAP
P12 | VDD_SNVS_IN
G8 | VDD_SOC_CAP
H8 | VDD_SOC_CAP
J8 | VDD_SOC_CAP
J11 | VDD_SOC_CAP
K8 | VDD_SOC_CAP
K11 | VDD_SOC_CAP
L8 | VDD_SOC_CAP
L9 | VDD_SOC_CAP
L10 | VDD_SOC_CAP
L11 | VDD_SOC_CAP
H9 | VDD_SOC_IN
H10 | VDD_SOC_IN
J9 | VDD_SOC_IN
J10 | VDD_SOC_IN
K9 | VDD_SOC_IN
K10 | VDD_SOC_IN
R12 | VDD_USB_CAP
L13 | VDDA_ADC_3P3
A1 | VSS
A17 | VSS
C3 | VSS
C7 | VSS
C11 | VSS
C15 | VSS
E8 | VSS
E11 | VSS
F6 | VSS
F7 | VSS
F8 | VSS
F9 | VSS
F10 | VSS
F11 | VSS
F12 | VSS
G3 | VSS
G5 | VSS
G7 | VSS
G12 | VSS
G15 | VSS
H7 | VSS
H12 | VSS
J5 | VSS
J7 | VSS
J12 | VSS
K7 | VSS
K12 | VSS
L3 | VSS
L7 | VSS
L12 | VSS
M7 | VSS
M8 | VSS
M9 | VSS
M10 | VSS
M11 | VSS
N3 | VSS
N5 | VSS
R3 | VSS
R5 | VSS
R7 | VSS
R11 | VSS
R16 | VSS
R17 | VSS
T14 | VSS
U1 | VSS
U14 | VSS
U17 | VSS
GPIO
Ball Position | Ball Name | Power Group | Input / Output | Ball Type | Default Mode | Default Function | Value
T10 | BOOT_MODE0 | VDD_SNVS_IN | Input | GPIO | ALT5 | GPIO5_IO10 | 100 KΩ pull-down
U10 | BOOT_MODE1 | VDD_SNVS_IN | Input | GPIO | ALT5 | GPIO5_IO11 | 100 KΩ pull-down
P16 | CCM_CLK1_N | VDD_HIGH_CAP | — | CCM | — | CCM_CLK1_N | —
P17 | CCM_CLK1_P | VDD_HIGH_CAP | — | CCM | — | CCM_CLK1_P | —
U9 | CCM_PMIC_STBY_REQ | VDD_SNVS_IN | Output | CCM | ALT0 | CCM_PMIC_VSTBY_REQ | —
E4 | CSI_DATA00 | NVCC_CSI | Input | GPIO | ALT5 | GPIO4_IO21 | Keeper
E3 | CSI_DATA01 | NVCC_CSI | Input | GPIO | ALT5 | GPIO4_IO22 | Keeper
E2 | CSI_DATA02 | NVCC_CSI | Input | GPIO | ALT5 | GPIO4_IO23 | Keeper
E1 | CSI_DATA03 | NVCC_CSI | Input | GPIO | ALT5 | GPIO4_IO24 | Keeper
D4 | CSI_DATA04 | NVCC_CSI | Input | GPIO | ALT5 | GPIO4_IO25 | Keeper
D3 | CSI_DATA05 | NVCC_CSI | Input | GPIO | ALT5 | GPIO4_IO26 | Keeper
D2 | CSI_DATA06 | NVCC_CSI | Input | GPIO | ALT5 | GPIO4_IO27 | Keeper
D1 | CSI_DATA07 | NVCC_CSI | Input | GPIO | ALT5 | GPIO4_IO28 | Keeper
F3 | CSI_HSYNC | NVCC_CSI | Input | GPIO | ALT5 | GPIO4_IO20 | Keeper
F5 | CSI_MCLK | NVCC_CSI | Input | GPIO | ALT5 | GPIO4_IO17 | Keeper
E5 | CSI_PIXCLK | NVCC_CSI | Input | GPIO | ALT5 | GPIO4_IO18 | Keeper
F2 | CSI_VSYNC | NVCC_CSI | Input | GPIO | ALT5 | GPIO4_IO19 | Keeper
L5 | DRAM_ADDR00 | NVCC_DRAM | Output | MMDC | ALT0 | DRAM_ADDR00 | 100 KΩ pull-up
H2 | DRAM_ADDR01 | NVCC_DRAM | Output | DDR | ALT0 | DRAM_ADDR01 | 100 KΩ pull-up
K1 | DRAM_ADDR02 | NVCC_DRAM | Output | DDR | ALT0 | DRAM_ADDR02 | 100 KΩ pull-up
M2 | DRAM_ADDR03 | NVCC_DRAM | Output | DDR | ALT0 | DRAM_ADDR03 | 100 KΩ pull-up
K4 | DRAM_ADDR04 | NVCC_DRAM | Output | DDR | ALT0 | DRAM_ADDR04 | 100 KΩ pull-up
L1 | DRAM_ADDR05 | NVCC_DRAM | Output | DDR | ALT0 | DRAM_ADDR05 | 100 KΩ pull-up
G2 | DRAM_ADDR06 | NVCC_DRAM | Output | DDR | ALT0 | DRAM_ADDR06 | 100 KΩ pull-up
H4 | DRAM_ADDR07 | NVCC_DRAM | Output | DDR | ALT0 | DRAM_ADDR07 | 100 KΩ pull-up
J4 | DRAM_ADDR08 | NVCC_DRAM | Output | DDR | ALT0 | DRAM_ADDR08 | 100 KΩ pull-up
L2 | DRAM_ADDR09 | NVCC_DRAM | Output | DDR | ALT0 | DRAM_ADDR09 | 100 KΩ pull-up
M4 | DRAM_ADDR10 | NVCC_DRAM | Output | DDR | ALT0 | DRAM_ADDR10 | 100 KΩ pull-up
K3 | DRAM_ADDR11 | NVCC_DRAM | Output | DDR | ALT0 | DRAM_ADDR11 | 100 KΩ pull-up
L4 | DRAM_ADDR12 | NVCC_DRAM | Output | DDR | ALT0 | DRAM_ADDR12 | 100 KΩ pull-up
H3 | DRAM_ADDR13 | NVCC_DRAM | Output | DDR | ALT0 | DRAM_ADDR13 | 100 KΩ pull-up
G1 | DRAM_ADDR14 | NVCC_DRAM | Output | DDR | ALT0 | DRAM_ADDR14 | 100 KΩ pull-up
K5 | DRAM_ADDR15 | NVCC_DRAM | Output | DDR | ALT0 | DRAM_ADDR15 | 100 KΩ pull-up
J2 | DRAM_CAS_B | NVCC_DRAM | Output | DDR | ALT0 | DRAM_CAS_B | 100 KΩ pull-up
N2 | DRAM_CS0_B | NVCC_DRAM | Output | DDR | ALT0 | DRAM_CS0_B | 100 KΩ pull-up
H5 | DRAM_CS1_B | NVCC_DRAM | Output | DDR | ALT0 | DRAM_CS1_B | 100 KΩ pull-up
T4 | DRAM_DATA00 | NVCC_DRAM | Input | DDR | ALT0 | DRAM_DATA00 | 100 KΩ pull-up
U6 | DRAM_DATA01 | NVCC_DRAM | Input | DDR | ALT0 | DRAM_DATA01 | 100 KΩ pull-up
T6 | DRAM_DATA02 | NVCC_DRAM | Input | DDR | ALT0 | DRAM_DATA02 | 100 KΩ pull-up
U7 | DRAM_DATA03 | NVCC_DRAM | Input | DDR | ALT0 | DRAM_DATA03 | 100 KΩ pull-up
U8 | DRAM_DATA04 | NVCC_DRAM | Input | DDR | ALT0 | DRAM_DATA04 | 100 KΩ pull-up
T8 | DRAM_DATA05 | NVCC_DRAM | Input | DDR | ALT0 | DRAM_DATA05 | 100 KΩ pull-up
T5 | DRAM_DATA06 | NVCC_DRAM | Input | DDR | ALT0 | DRAM_DATA06 | 100 KΩ pull-up
U4 | DRAM_DATA07 | NVCC_DRAM | Input | DDR | ALT0 | DRAM_DATA07 | 100 KΩ pull-up
U2 | DRAM_DATA08 | NVCC_DRAM | Input | DDR | ALT0 | DRAM_DATA08 | 100 KΩ pull-up
U3 | DRAM_DATA09 | NVCC_DRAM | Input | DDR | ALT0 | DRAM_DATA09 | 100 KΩ pull-up
U5 | DRAM_DATA10 | NVCC_DRAM | Input | DDR | ALT0 | DRAM_DATA10 | 100 KΩ pull-up
R4 | DRAM_DATA11 | NVCC_DRAM | Input | DDR | ALT0 | DRAM_DATA11 | 100 KΩ pull-up
P5 | DRAM_DATA12 | NVCC_DRAM | Input | DDR | ALT0 | DRAM_DATA12 | 100 KΩ pull-up
P3 | DRAM_DATA13 | NVCC_DRAM | Input | DDR | ALT0 | DRAM_DATA13 | 100 KΩ pull-up
R2 | DRAM_DATA14 | NVCC_DRAM | Input | DDR | ALT0 | DRAM_DATA14 | 100 KΩ pull-up
R1 | DRAM_DATA15 | NVCC_DRAM | Input | DDR | ALT0 | DRAM_DATA15 | 100 KΩ pull-up
T7 | DRAM_DQM0 | NVCC_DRAM | Output | DDR | ALT0 | DRAM_DQM0 | 100 KΩ pull-up
T3 | DRAM_DQM1 | NVCC_DRAM | Output | DDR | ALT0 | DRAM_DQM1 | 100 KΩ pull-up
N1 | DRAM_ODT0 | NVCC_DRAM | Output | DDR | ALT0 | DRAM_ODT0 | 100 KΩ pull-down
F1 | DRAM_ODT1 | NVCC_DRAM | Output | DDR | ALT0 | DRAM_ODT1 | 100 KΩ pull-down
M5 | DRAM_RAS_B | NVCC_DRAM | Output | DDR | ALT0 | DRAM_RAS_B | 100 KΩ pull-up
G4 | DRAM_RESET | NVCC_DRAM | Output | DDR | ALT0 | DRAM_RESET | 100 KΩ pull-down
M1 | DRAM_SDBA0 | NVCC_DRAM | Output | DDR | ALT0 | DRAM_SDBA0 | 100 KΩ pull-up
H1 | DRAM_SDBA1 | NVCC_DRAM | Output | DDR | ALT0 | DRAM_SDBA1 | 100 KΩ pull-up
K2 | DRAM_SDBA2 | NVCC_DRAM | Output | DDR | ALT0 | DRAM_SDBA2 | 100 KΩ pull-up
M3 | DRAM_SDCKE0 | NVCC_DRAM | Output | DDR | ALT0 | DRAM_SDCKE0 | 100 KΩ pull-down
J3 | DRAM_SDCKE1 | NVCC_DRAM | Output | DDR | ALT0 | DRAM_SDCKE1 | 100 KΩ pull-down
P2 | DRAM_SDCLK0_N | NVCC_DRAM | Input | DDRCLK | ALT0 | DRAM_SDCLK0_N | 100 KΩ pull-up
P1 | DRAM_SDCLK0_P | NVCC_DRAM | Input | DDRCLK | ALT0 | DRAM_SDCLK0_P | 100 KΩ pull-up
P7 | DRAM_SDQS0_N | NVCC_DRAM | Input | DDRCLK | ALT0 | DRAM_SDQS0_N | 100 KΩ pull-down
P6 | DRAM_SDQS0_P | NVCC_DRAM | Input | DDRCLK | ALT0 | DRAM_SDQS0_P | 100 KΩ pull-down
T2 | DRAM_SDQS1_N | NVCC_DRAM | Input | DDRCLK | ALT0 | DRAM_SDQS1_N | 100 KΩ pull-down
T1 | DRAM_SDQS1_P | NVCC_DRAM | Input | DDRCLK | ALT0 | DRAM_SDQS1_P | 100 KΩ pull-down
J1 | DRAM_SDWE_B | NVCC_DRAM | Output | DDR | ALT0 | DRAM_SDWE_B | 100 KΩ pull-up
N4 | DRAM_ZQPAD | NVCC_DRAM | Input | GPIO | — | DRAM_ZQPAD | Keeper
F16 | ENET1_RX_DATA0 | NVCC_ENET | Input | GPIO | ALT5 | GPIO2_IO0 | Keeper
E17 | ENET1_RX_DATA1 | NVCC_ENET | Input | GPIO | ALT5 | GPIO2_IO1 | Keeper
E16 | ENET1_RX_EN | NVCC_ENET | Input | GPIO | ALT5 | GPIO2_IO2 | Keeper
D15 | ENET1_RX_ER | NVCC_ENET | Input | GPIO | ALT5 | GPIO2_IO7 | Keeper
F14 | ENET1_TX_CLK | NVCC_ENET | Input | GPIO | ALT5 | GPIO2_IO6 | Keeper
E15 | ENET1_TX_DATA0 | NVCC_ENET | Input | GPIO | ALT5 | GPIO2_IO3 | Keeper
E14 | ENET1_TX_DATA1 | NVCC_ENET | Input | GPIO | ALT5 | GPIO2_IO4 | Keeper
F15 | ENET1_TX_EN | NVCC_ENET | Input | GPIO | ALT5 | GPIO2_IO5 | Keeper
C17 | ENET2_RX_DATA0 | NVCC_ENET | Input | GPIO | ALT5 | GPIO2_IO8 | Keeper
C16 | ENET2_RX_DATA1 | NVCC_ENET | Input | GPIO | ALT5 | GPIO2_IO9 | Keeper
B17 | ENET2_RX_EN | NVCC_ENET | Input | GPIO | ALT5 | GPIO2_IO10 | Keeper
D16 | ENET2_RX_ER | NVCC_ENET | Input | GPIO | ALT5 | GPIO2_IO15 | Keeper
D17 | ENET2_TX_CLK | NVCC_ENET | Input | GPIO | ALT5 | GPIO2_IO14 | Keeper
A15 | ENET2_TX_DATA0 | NVCC_ENET | Input | GPIO | ALT5 | GPIO2_IO11 | Keeper
A16 | ENET2_TX_DATA1 | NVCC_ENET | Input | GPIO | ALT5 | GPIO2_IO12 | Keeper
B15 | ENET2_TX_EN | NVCC_ENET | Input | GPIO | ALT5 | GPIO2_IO13 | Keeper
K13 | GPIO1_IO00 | NVCC_GPIO | Input | GPIO | ALT5 | GPIO1_IO00 | Keeper
L15 | GPIO1_IO01 | NVCC_GPIO | Input | GPIO | ALT5 | GPIO1_IO01 | Keeper
L14 | GPIO1_IO02 | NVCC_GPIO | Input | GPIO | ALT5 | GPIO1_IO02 | Keeper
L17 | GPIO1_IO03 | NVCC_GPIO | Input | GPIO | ALT5 | GPIO1_IO03 | Keeper
M16 | GPIO1_IO04 | NVCC_GPIO | Input | GPIO | ALT5 | GPIO1_IO04 | Keeper
M17 | GPIO1_IO05 | NVCC_GPIO | Input | GPIO | ALT5 | GPIO1_IO05 | Keeper
K17 | GPIO1_IO06 | NVCC_GPIO | Input | GPIO | ALT5 | GPIO1_IO06 | Keeper
L16 | GPIO1_IO07 | NVCC_GPIO | Input | GPIO | ALT5 | GPIO1_IO07 | Keeper
N17 | GPIO1_IO08 | NVCC_GPIO | Input | GPIO | ALT5 | GPIO1_IO08 | Keeper
M15 | GPIO1_IO09 | NVCC_GPIO | Input | GPIO | ALT5 | GPIO1_IO09 | Keeper
P15 | JTAG_MOD | NVCC_GPIO | Input | SJC | ALT0 | SJC_MOD | 100 KΩ pull-up
M14 | JTAG_TCK | NVCC_GPIO | Input | SJC | ALT0 | SJC_TCK | 47 KΩ pull-up
N16 | JTAG_TDI | NVCC_GPIO | Input | SJC | ALT0 | SJC_TDI | 47 KΩ pull-up
N15 | JTAG_TDO | NVCC_GPIO | Output | SJC | ALT0 | SJC_TDO | Keeper
P14 | JTAG_TMS | NVCC_GPIO | Input | SJC | ALT0 | SJC_TMS | 47 KΩ pull-up
N14 | JTAG_TRST_B | NVCC_GPIO | Input | SJC | ALT0 | SJC_TRSTB | 47 KΩ pull-up
A8 | LCD_CLK | NVCC_LCD | Input | GPIO | ALT5 | GPIO3_IO0 | Keeper
B9 | LCD_DATA00 | NVCC_LCD | Input | GPIO | ALT5 | GPIO3_IO5 | Keeper
A9 | LCD_DATA01 | NVCC_LCD | Input | GPIO | ALT5 | GPIO3_IO6 | Keeper
E10 | LCD_DATA02 | NVCC_LCD | Input | GPIO | ALT5 | GPIO3_IO7 | Keeper
D10 | LCD_DATA03 | NVCC_LCD | Input | GPIO | ALT5 | GPIO3_IO8 | Keeper
C10 | LCD_DATA04 | NVCC_LCD | Input | GPIO | ALT5 | GPIO3_IO9 | Keeper
B10 | LCD_DATA05 | NVCC_LCD | Input | GPIO | ALT5 | GPIO3_IO10 | Keeper
A10 | LCD_DATA06 | NVCC_LCD | Input | GPIO | ALT5 | GPIO3_IO11 | Keeper
D11 | LCD_DATA07 | NVCC_LCD | Input | GPIO | ALT5 | GPIO3_IO12 | Keeper
B11 | LCD_DATA08 | NVCC_LCD | Input | GPIO | ALT5 | GPIO3_IO13 | Keeper
A11 | LCD_DATA09 | NVCC_LCD | Input | GPIO | ALT5 | GPIO3_IO14 | Keeper
E12 | LCD_DATA10 | NVCC_LCD | Input | GPIO | ALT5 | GPIO3_IO15 | Keeper
D12 | LCD_DATA11 | NVCC_LCD | Input | GPIO | ALT5 | GPIO3_IO16 | Keeper
C12 | LCD_DATA12 | NVCC_LCD | Input | GPIO | ALT5 | GPIO3_IO17 | Keeper
B12 | LCD_DATA13 | NVCC_LCD | Input | GPIO | ALT5 | GPIO3_IO18 | Keeper
A12 | LCD_DATA14 | NVCC_LCD | Input | GPIO | ALT5 | GPIO3_IO19 | Keeper
D13 | LCD_DATA15 | NVCC_LCD | Input | GPIO | ALT5 | GPIO3_IO20 | Keeper
C13 | LCD_DATA16 | NVCC_LCD | Input | GPIO | ALT5 | GPIO3_IO21 | Keeper
B13 | LCD_DATA17 | NVCC_LCD | Input | GPIO | ALT5 | GPIO3_IO22 | Keeper
A13 | LCD_DATA18 | NVCC_LCD | Input | GPIO | ALT5 | GPIO3_IO23 | Keeper
D14 | LCD_DATA19 | NVCC_LCD | Input | GPIO | ALT5 | GPIO3_IO24 | Keeper
C14 | LCD_DATA20 | NVCC_LCD | Input | GPIO | ALT5 | GPIO3_IO25 | Keeper
B14 | LCD_DATA21 | NVCC_LCD | Input | GPIO | ALT5 | GPIO3_IO26 | Keeper
A14 | LCD_DATA22 | NVCC_LCD | Input | GPIO | ALT5 | GPIO3_IO27 | Keeper
B16 | LCD_DATA23 | NVCC_LCD | Input | GPIO | ALT5 | GPIO3_IO28 | Keeper
B8 | LCD_ENABLE | NVCC_LCD | Input | GPIO | ALT5 | GPIO3_IO1 | Keeper
D9 | LCD_HSYNC | NVCC_LCD | Input | GPIO | ALT5 | GPIO3_IO2 | Keeper
E9 | LCD_RESET | NVCC_LCD | Input | GPIO | ALT5 | GPIO3_IO4 | Keeper
C9 | LCD_VSYNC | NVCC_LCD | Input | GPIO | ALT5 | GPIO3_IO3 | Keeper
B4 | NAND_ALE | NVCC_NAND | Input | GPIO | ALT5 | GPIO4_IO10 | Keeper
C5 | NAND_CE0_B | NVCC_NAND | Input | GPIO | ALT5 | GPIO4_IO13 | Keeper
B5 | NAND_CE1_B | NVCC_NAND | Input | GPIO | ALT5 | GPIO4_IO14 | Keeper
A4 | NAND_CLE | NVCC_NAND | Input | GPIO | ALT5 | GPIO4_IO15 | Keeper
D7 | NAND_DATA00 | NVCC_NAND | Input | GPIO | ALT5 | GPIO4_IO2 | Keeper
B7 | NAND_DATA01 | NVCC_NAND | Input | GPIO | ALT5 | GPIO4_IO3 | Keeper
A7 | NAND_DATA02 | NVCC_NAND | Input | GPIO | ALT5 | GPIO4_IO4 | Keeper
D6 | NAND_DATA03 | NVCC_NAND | Input | GPIO | ALT5 | GPIO4_IO5 | Keeper
C6 | NAND_DATA04 | NVCC_NAND | Input | GPIO | ALT5 | GPIO4_IO6 | Keeper
B6 | NAND_DATA05 | NVCC_NAND | Input | GPIO | ALT5 | GPIO4_IO7 | Keeper
A6 | NAND_DATA06 | NVCC_NAND | Input | GPIO | ALT5 | GPIO4_IO8 | Keeper
A5 | NAND_DATA07 | NVCC_NAND | Input | GPIO | ALT5 | GPIO4_IO9 | Keeper
E6 | NAND_DQS | NVCC_NAND | Input | GPIO | ALT5 | GPIO4_IO16 | Keeper
D8 | NAND_RE_B | NVCC_NAND | Input | GPIO | ALT5 | GPIO4_IO0 | Keeper
A3 | NAND_READY_B | NVCC_NAND | Input | GPIO | ALT5 | GPIO4_IO12 | Keeper
C8 | NAND_WE_B | NVCC_NAND | Input | GPIO | ALT5 | GPIO4_IO1 | Keeper
D5 | NAND_WP_B | NVCC_NAND | Input | GPIO | ALT5 | GPIO4_IO11 | Keeper
R8 | ONOFF | VDD_SNVS_IN | Input | SRC | ALT0 | SRC_RESET_B | 100 KΩ pull-up
P8 | POR_B | VDD_SNVS_IN | Input | SRC | ALT0 | SRC_POR_B | 100 KΩ pull-up
T11 | RTC_XTALI | VDD_SNVS_CAP | — | ANALOG | — | RTC_XTALI | —
U11 | RTC_XTALO | VDD_SNVS_CAP | — | ANALOG | — | RTC_XTALO | —
C1 | SD1_CLK | NVCC_SD | Input | GPIO | ALT5 | GPIO2_IO17 | Keeper
C2 | SD1_CMD | NVCC_SD | Input | GPIO | ALT5 | GPIO2_IO16 | Keeper
B3 | SD1_DATA0 | NVCC_SD | Input | GPIO | ALT5 | GPIO2_IO18 | Keeper
B2 | SD1_DATA1 | NVCC_SD | Input | GPIO | ALT5 | GPIO2_IO19 | Keeper
B1 | SD1_DATA2 | NVCC_SD | Input | GPIO | ALT5 | GPIO2_IO20 | Keeper
A2 | SD1_DATA3 | NVCC_SD | Input | GPIO | ALT5 | GPIO2_IO21 | Keeper
T9 | SNVS_PMIC_ON_REQ | VDD_SNVS_IN | Output | GPIO | ALT0 | SNVS_PMIC_ON_REQ | 100 KΩ pull-up
R10 | SNVS_TAMPER0 | VDD_SNVS_IN | Input | GPIO | ALT5 | GPIO5_IO00/SNVS_TAMPER01 | Keeper/Notconnected 1,2
R9 | SNVS_TAMPER1 | VDD_SNVS_IN | Input | GPIO | ALT5 | GPIO5_IO01/SNVS_TAMPER11 | Keeper/Notconnected 1,2
P11 | SNVS_TAMPER2 | VDD_SNVS_IN | Input | GPIO | ALT5 | GPIO5_IO02/SNVS_TAMPER21 | Keeper/Notconnected 1,2
P10 | SNVS_TAMPER3 | VDD_SNVS_IN | Input | GPIO | ALT5 | GPIO5_IO03/SNVS_TAMPER31 | Keeper/Notconnected 1,2
P9 | SNVS_TAMPER4 | VDD_SNVS_IN | Input | GPIO | ALT5 | GPIO5_IO04/SNVS_TAMPER41 | Keeper/Notconnected 1,2
N8 | SNVS_TAMPER5 | VDD_SNVS_IN | Input | GPIO | ALT5 | GPIO5_IO05/SNVS_TAMPER51 | Keeper/Notconnected 1,2
N11 | SNVS_TAMPER6 | VDD_SNVS_IN | Input | GPIO | ALT5 | GPIO5_IO06/SNVS_TAMPER61 | Keeper/Notconnected 1,2
N10 | SNVS_TAMPER7 | VDD_SNVS_IN | Input | GPIO | ALT5 | GPIO5_IO07/SNVS_TAMPER71 | Keeper/Notconnected 1,2
N9 | SNVS_TAMPER8 | VDD_SNVS_IN | Input | GPIO | ALT5 | GPIO5_IO08/SNVS_TAMPER81 | Keeper/Notconnected 1,2
R6 | SNVS_TAMPER9 | VDD_SNVS_IN | Input | GPIO | ALT5 | GPIO5_IO09/SNVS_TAMPER91 | Keeper/Notconnected 1,2
N7 | TEST_MODE | VDD_SNVS_IN | Input | TCU | ALT0 | TCU_TEST_MODE | Keeper
K15 | UART1_CTS_B | NVCC_UART | Input | GPIO | ALT5 | GPIO1_IO18 | Keeper
J14 | UART1_RTS_B | NVCC_UART | Input | GPIO | ALT5 | GPIO1_IO19 | Keeper
K16 | UART1_RX_DATA | NVCC_UART | Input | GPIO | ALT5 | GPIO1_IO17 | Keeper
K14 | UART1_TX_DATA | NVCC_UART | Input | GPIO | ALT5 | GPIO1_IO16 | Keeper
J15 | UART2_CTS_B | NVCC_UART | Input | GPIO | ALT5 | GPIO1_IO22 | Keeper
H14 | UART2_RTS_B | NVCC_UART | Input | GPIO | ALT5 | GPIO1_IO23 | Keeper
J16 | UART2_RX_DATA | NVCC_UART | Input | GPIO | ALT5 | GPIO1_IO21 | Keeper
J17 | UART2_TX_DATA | NVCC_UART | Input | GPIO | ALT5 | GPIO1_IO20 | Keeper
H15 | UART3_CTS_B | NVCC_UART | Input | GPIO | ALT5 | GPIO1_IO26 | Keeper
G14 | UART3_RTS_B | NVCC_UART | Input | GPIO | ALT5 | GPIO1_IO27 | Keeper
H16 | UART3_RX_DATA | NVCC_UART | Input | GPIO | ALT5 | GPIO1_IO25 | Keeper
H17 | UART3_TX_DATA | NVCC_UART | Input | GPIO | ALT5 | GPIO1_IO24 | Keeper
G16 | UART4_RX_DATA | NVCC_UART | Input | GPIO | ALT5 | GPIO1_IO29 | Keeper
G17 | UART4_TX_DATA | NVCC_UART | Input | GPIO | ALT5 | GPIO1_IO28 | Keeper
G13 | UART5_RX_DATA | NVCC_UART | Input | GPIO | ALT5 | GPIO1_IO31 | Keeper
F17 | UART5_TX_DATA | NVCC_UART | Input | GPIO | ALT5 | GPIO1_IO30 | Keeper
U16 | USB_OTG1_CHD_B | OPEN DRAIN | — | GPIO | — | USB_OTG1_CHD_B | —
T15 | USB_OTG1_DN | VDD_USB_CAP | — | ANALOG | — | USB_OTG1_DN | —
U15 | USB_OTG1_DP | VDD_USB_CAP | — | ANALOG | — | USB_OTG1_DP | —
T12 | USB_OTG1_VBUS | USB_VBUS | — | VBUS POWER | — | USB_OTG1_VBUS | —
T13 | USB_OTG2_DN | VDD_USB_CAP | — | ANALOG | — | USB_OTG2_DN | —
U13 | USB_OTG2_DP | VDD_USB_CAP | — | ANALOG | — | USB_OTG2_DP | —
U12 | USB_OTG2_VBUS | USB_VBUS | — | VBUS POWER | — | USB_OTG2_VBUS | —
T16 | XTALI | NVCC_PLL | — | ANALOG | — | XTALI | —
T17 | XTALO | NVCC_PLL | — | ANALOG | — | XTALO | —

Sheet: Foglio2
NAME | Default | ALT0 | ALT1 | ALT2 | ALT3 | ALT4 | ALT5 | ALT6 | ALT7 | ALT8 | ALT9 | PAD DFU
TEST_MODE | tcu.TEST_MODE | tcu.TEST_MODE |  |  |  |  |  |  |  |  |  | 100K PD
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

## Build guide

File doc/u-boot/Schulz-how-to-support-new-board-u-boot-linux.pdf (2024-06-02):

## Embedded Linux Conference Europe 2017

# Porting U-Boot and Linux on new ARM boards:

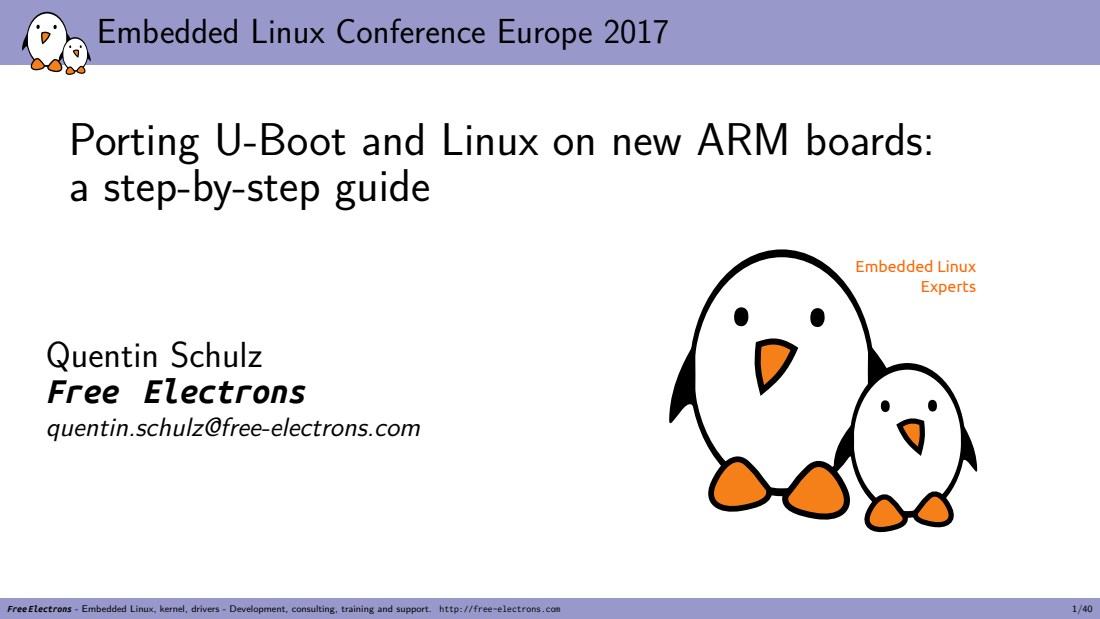
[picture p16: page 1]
Embedded Linux Experts; Free Electrons - Embedded Linux, kernel, drivers - Development, consulting, training and support. http://free-electrons.com

a step-by-step guide

Quentin Schulz
Free Electrons
quentin.schulz@free-electrons.com

## Quentin Schulz

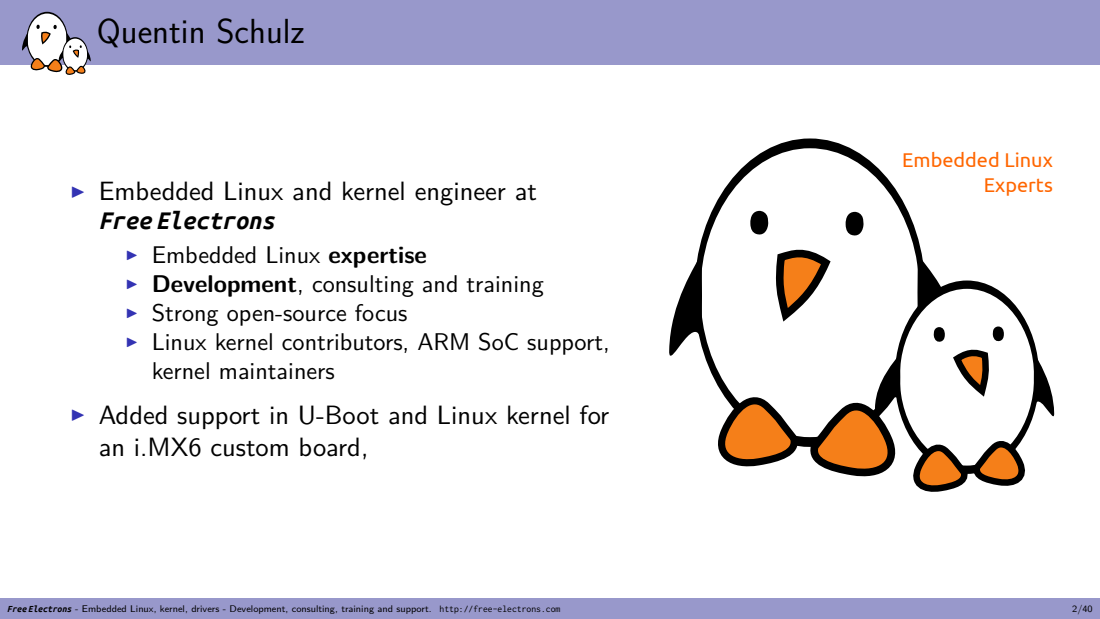
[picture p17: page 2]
Embedded Linux Experts; Free Electrons - Embedded Linux, kernel, drivers - Development, consulting, training and support. http://free-electrons.com

▶ Embedded Linux and kernel engineer at
Free Electrons
▶ Embedded Linux expertise
▶ Development, consulting and training
▶ Strong open-source focus
▶ Linux kernel contributors, ARM SoC support,
kernel maintainers

▶ Added support in U-Boot and Linux kernel for
an i.MX6 custom board,

- Feedback from my journey to support a custom board in U-Boot and Linux,
- Examples for a board with a well-known SoC (i.MX6) and already supported IPs, almost no coding skill involved in this talk,
- More focused on the U-Boot part,
Free Electrons - Embedded Linux, kernel, drivers - Development, consulting, training and support. http://free-electrons.com | 3/40

- If you have the sources of your BSP, compile and run the BSP to:
1. Validate the IP you’re working on works with some code,
2. Have a reference code,
3. Have a code that you can use to debug,
- Focus on correctly configuring RAM and UART only,
- Commit,
- One IP at a time,
- Commit,
Free Electrons - Embedded Linux, kernel, drivers - Development, consulting, training and support. http://free-electrons.com | 4/40

- i.MX6-based module with an extension board,
- Ethernet, I2C, SPI, NAND, eMMC, SD Card reader, USB device, EEPROM, GPIO, UART, audio (I2S), HDMI, LVDS, PCIe, USB host, RTC, PMIC,
Free Electrons - Embedded Linux, kernel, drivers - Development, consulting, training and support. http://free-electrons.com | 5/40

## Embedded Linux Conference Europe 2017

# U-Boot porting

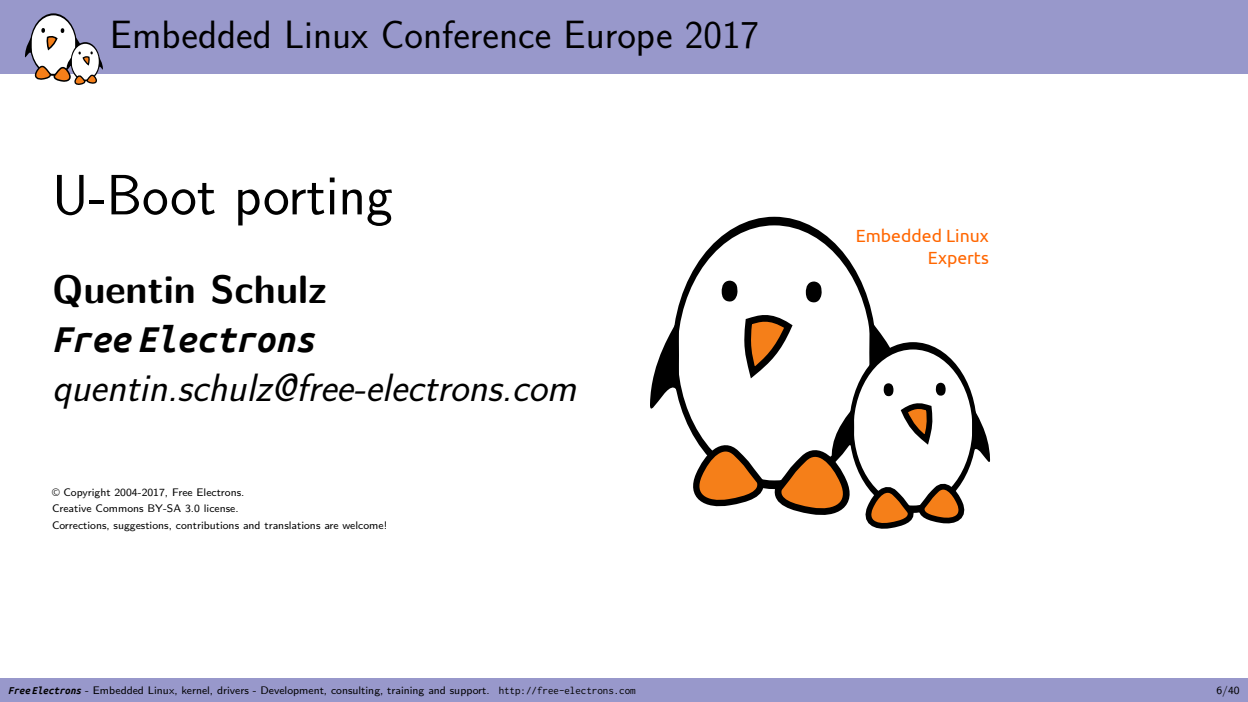
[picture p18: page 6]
Embedded Linux Experts; Free Electrons - Embedded Linux, kernel, drivers - Development, consulting, training and support. http://free-electrons.com

Quentin Schulz
Free Electrons
quentin.schulz@free-electrons.com

© Copyright 2004-2017, Free Electrons.
Creative Commons BY-SA 3.0 license.
Corrections, suggestions, contributions and translations are welcome!

- On-going migration from board header file defines to Kconfig options,
- On-going migration from manual drivers probing to Driver Model,
Free Electrons - Embedded Linux, kernel, drivers - Development, consulting, training and support. http://free-electrons.com | 7/40

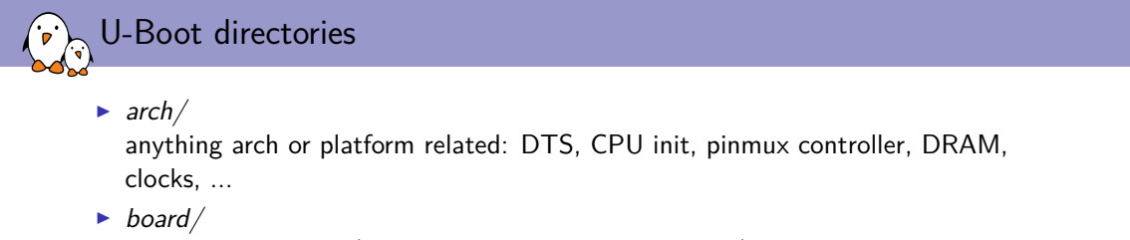
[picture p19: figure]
U-Boot directories; ▶ arch/; clocks, ... ▶ board/

anything arch or platform related: DTS, CPU init, pinmux controller, DRAM,

code board specific (init, pinmuxing configuration, etc), Kconfig file specifying board header file, board file, paths, Makefile for board file,
- configs/
all boards’ defconfigs
- drivers/
- include/
all headers
- include/configs/
all boards’ header files
Free Electrons - Embedded Linux, kernel, drivers - Development, consulting, training and support. http://free-electrons.com | 8/40

1. Create the board file,
2. Create the board Kconfig file,
3. Create the board Makefile,
4. Create the board defconfig,
5. Create the board header file,
6. Source board’s Kconfig in the architecture’s Kconfig,
7. Define the TARGET Kconfig option in its CPU’s Kconfig,
- some platforms (e.g. sunxi (Allwinner)) share common files so only a defconfig would be required,
Free Electrons - Embedded Linux, kernel, drivers - Development, consulting, training and support. http://free-electrons.com | 9/40

board/my_vendor/my_board/my_board.c

#include <...>

DECLARE_GLOBAL_DATA_PTR;

int dram_init(void)
{
gd->ram_size = imx_ddr_size(); return 0;
}

int board_init(void)
{
return 0;
}
Free Electrons - Embedded Linux, kernel, drivers - Development, consulting, training and support. http://free-electrons.com | 10/40

- DECLARE_GLOBAL_DATA_PTR,
- usable in code with gd global variable,
- on ARM, equals to hardware register r9 for ARM32 and x18 for ARM64,
- used to store info in ”some memory which is available very early after boot to allow for a minimum set of global variables during system initialization (until we have set up the memory controller so that we can use RAM)”,
- include/asm-generic/global_data.h to find what kind of information it can store,
Free Electrons - Embedded Linux, kernel, drivers - Development, consulting, training and support. http://free-electrons.com | 11/40

board/my_vendor/my_board/Kconfig

if TARGET_MY_BOARD

config SYS_BOARD
default "my_board"

config SYS_VENDOR
default "my_vendor"

config SYS_CONFIG_NAME
default "my_board"

endif

Free Electrons - Embedded Linux, kernel, drivers - Development, consulting, training and support. http://free-electrons.com | 12/40

- SYS_VENDOR and SYS_BOARD are used to identify the directory where make find the files it needs to compile,
- if both are present,
- board/SYS_VENDOR/SYS_BOARD/
- if SYS_VENDOR is omitted,
- board/SYS_BOARD/
- if SYS_BOARD is omitted,
- board/SYS_VENDOR/common/
- SYS_CONFIG_NAME is used to identify the board header file,
- include/configs/SYS_CONFIG_NAME.h
Free Electrons - Embedded Linux, kernel, drivers - Development, consulting, training and support. http://free-electrons.com | 13/40

board/my_vendor/my_board/Makefile

obj-y := my_board.o

Free Electrons - Embedded Linux, kernel, drivers - Development, consulting, training and support. http://free-electrons.com | 14/40

configs/my_board_defconfig

CONFIG_ARM=y
CONFIG_ARCH_MX6=y
CONFIG_TARGET_MY_BOARD=y
CONFIG_MXC_UART=y
Free Electrons - Embedded Linux, kernel, drivers - Development, consulting, training and support. http://free-electrons.com | 15/40

- put here anything that is selectable in Kconfig (menuconfig),
- drivers, features, U-Boot behaviour, libs, etc.
Free Electrons - Embedded Linux, kernel, drivers - Development, consulting, training and support. http://free-electrons.com | 16/40

## 5. Create the board header file (minimal example for i.MX6 Solo)

include/configs/my_board.h

#ifndef __MY_BOARD_CONFIG_H__

#define __MY_BOARD_CONFIG_H__

#define CONFIG_MXC_UART_BASE | UART5_BASE

#include "mx6_common.h"

#define CONFIG_NR_DRAM_BANKS | 1

#define CONFIG_SYS_MAX_FLASH_BANKS | 1

#define CONFIG_SYS_MALLOC_LEN | (10 * SZ_1M)

#define CONFIG_SYS_FSL_ESDHC_ADDR | 0

#define PHYS_SDRAM | MMDC0_ARB_BASE_ADDR

#define CONFIG_SYS_SDRAM_BASE | PHYS_SDRAM

#define CONFIG_SYS_INIT_RAM_ADDR | IRAM_BASE_ADDR

#define CONFIG_SYS_INIT_RAM_SIZE | IRAM_SIZE

#define CONFIG_SYS_INIT_SP_OFFSET \ (CONFIG_SYS_INIT_RAM_SIZE - GENERATED_GBL_DATA_SIZE)

#define CONFIG_SYS_INIT_SP_ADDR \ (CONFIG_SYS_INIT_RAM_ADDR + CONFIG_SYS_INIT_SP_OFFSET)

#endif

Free Electrons - Embedded Linux, kernel, drivers - Development, consulting, training and support. http://free-electrons.com | 17/40

arch/arm/Kconfig or
arch/arm/mach-imx/mx6/Kconfig
source "board/imx31_phycore/Kconfig" source "board/isee/igep003x/Kconfig" source "board/my_vendor/my_board/Kconfig" source "board/olimex/mx23_olinuxino/Kconfig" source "board/phytec/pcm051/Kconfig"
Free Electrons - Embedded Linux, kernel, drivers - Development, consulting, training and support. http://free-electrons.com | 18/40

arch/arm/mach-imx/mx6/Kconfig

choice
config TARGET_MY_BOARD
bool "My awesome board"
select MX6S
endchoice
Free Electrons - Embedded Linux, kernel, drivers - Development, consulting, training and support. http://free-electrons.com | 19/40

- U-Boot will run two lists of functions whose purpose is to init or configure specific IPs before the user have access to the console,
- the first list is defined in common/board_f.c in the
static init_fnc_t init_sequence_f[] array,
- first list takes care of initialising DRAM, mapping it and relocating the bootloader code once it’s working,
- the second list is defined in common/board_r.c in the
static init_fnc_t init_sequence_r[] array,
- some functions are run only when a constant is defined (e.g. CONFIG_BOARD_EARLY_INIT_F defined to run board_early_init_f()),
- any function returning a non-zero value will stop the init sequence and make U-Boot fail to boot,
- define DEBUG when having trouble with init sequence,
- not all ”features” are available in all functions (i.e. no udelay in
board_early_init_f())
Free Electrons - Embedded Linux, kernel, drivers - Development, consulting, training and support. http://free-electrons.com | 20/40

- take inspiration from boards with the same IP,
- inspect drivers in the appropriate subsystem,
1. focus on the driver’s behaviour,
2. then check out the registers, bit offsets, masks, etc.
3. check for undefined macros or constants,
4. check for piece of code surrounded by ifdef blocks,
- look for the object file of this driver in the Makefile of the subsystem,

obj-$(CONFIG_MY_DRIVER) += my_driver.o
- grep for CONFIG_MY_DRIVER,
- visible symbol in some Kconfig file => add to board defconfig,
- non-visible symbol in some Kconfig file or not defined => board header file,
- make sure your driver is compiled (look for my_driver.o),
Free Electrons - Embedded Linux, kernel, drivers - Development, consulting, training and support. http://free-electrons.com | 21/40

- drivers/mtd/nand/nand_mxs.c,
- CONFIG_NAND_MXS for compiling the driver,
- CONFIG_SYS_MAX_NAND_DEVICE and CONFIG_SYS_NAND_BASE constants for configuring the device,
Free Electrons - Embedded Linux, kernel, drivers - Development, consulting, training and support. http://free-electrons.com | 22/40

configs/my_board_defconfig

CONFIG_ARM=y
CONFIG_ARCH_MX6=y
CONFIG_TARGET_MY_BOARD=y
CONFIG_MXC_UART=y
CONFIG_NAND_MXS=y
Free Electrons - Embedded Linux, kernel, drivers - Development, consulting, training and support. http://free-electrons.com | 23/40

include/configs/my_board.h
/* Define NAND settings */
/* Max number of NAND devices supported */
#define CONFIG_SYS_MAX_NAND_DEVICE | 1

#define CONFIG_SYS_NAND_BASE | 0x00112000

Free Electrons - Embedded Linux, kernel, drivers - Development, consulting, training and support. http://free-electrons.com | 24/40

board/my_vendor/my_board.c
static iomux_v3_cfg_t const nand_pads[] = {...}; ...
int board_init(void)
{
imx_iomux_v3_setup_multiple_pads(nand_pads, ARRAY_SIZE(nand_pads));

return 0;
}
Free Electrons - Embedded Linux, kernel, drivers - Development, consulting, training and support. http://free-electrons.com | 25/40

- the migration to Device Trees started back in 2012 and the code is slowly migrated, driver by driver, subsystem by subsystem,
- need for Driver model to use device trees,
- most drivers have big ifdef blocks for CONFIG_DM,
- you can’t really chose on a per-driver basis to enable DM support,
- idem for subsystem core code,
- I didn’t go really deep into it as we needed either no or full support for Device Trees and the NAND framework isn’t migrated to the DM,
Free Electrons - Embedded Linux, kernel, drivers - Development, consulting, training and support. http://free-electrons.com | 26/40

- Ethernet, EEPROM, NAND, eMMC, SD Card reader, USB device, GPIO, UART, audio (I2S), PMIC,

$ wc -l board/my_vendor/my_board/* configs/my_board_defconfig include/configs/my_board.h 15 board/my_vendor/my_board/Kconfig
8 board/my_vendor/my_board/Makefile
159 board/my_vendor/my_board/my_board.cfg #DCD conf for DDR controller and memory 218 board/my_vendor/my_board/my_board.c
39 configs/my_board_defconfig
110 include/configs/my_board.h
510 total
- +1 line in arch/arm/Kconfig,
- +4 lines in arch/arm/cpu/armv7/mx6/Kconfig,
- actually ~100 lines of ”real” code (PHY and board init, mmc configuration),
- no modification of U-Boot source code otherwise,
Free Electrons - Embedded Linux, kernel, drivers - Development, consulting, training and support. http://free-electrons.com | 27/40

- got some weird bug with the RSA lib when checking fitImage signatures in U-Boot,
- update from 2017.03 to 2017.07 was very easy:
- port board header file, board file, board Makefile, board Kconfig and update the Kconfig of the architecture,
- make sure options defined in board header files are not Kconfig options now,
- problem solved in ~30min by updating,
Free Electrons - Embedded Linux, kernel, drivers - Development, consulting, training and support. http://free-electrons.com | 28/40

- board init sequence is toggling a few GPIOs with a given timing,
- all signals (even UART) go through the FPGA,
- failing board init sequence, no FPGA, no UART, no hair left on my head,
- no udelay in board_early_init_f,
- a workaround was to use a forloop with cpurelax(),
Free Electrons - Embedded Linux, kernel, drivers - Development, consulting, training and support. http://free-electrons.com | 29/40

## Embedded Linux Conference Europe 2017

# Linux kernel porting

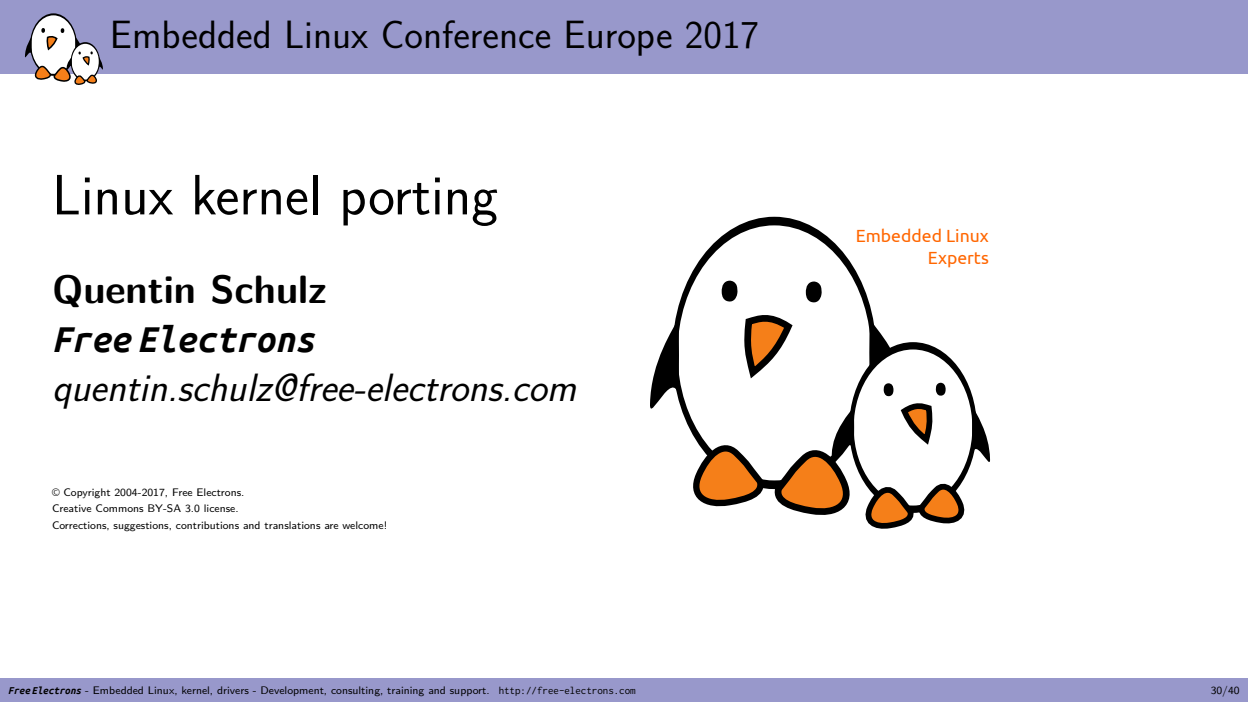
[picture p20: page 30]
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

Quentin Schulz
Free Electrons
quentin.schulz@free-electrons.com

© Copyright 2004-2017, Free Electrons.
Creative Commons BY-SA 3.0 license.
Corrections, suggestions, contributions and translations are welcome!

1. Create the board’s Device Tree,
2. Add your board’s DTB to the architecture DTS Makefile,
3. Create a defconfig for your board,
Free Electrons - Embedded Linux, kernel, drivers - Development, consulting, training and support. http://free-electrons.com | 31/40

- a file in a special DTS (Device Tree Source) format,
- purely describes the hardware of your board,
- matches an IP with a driver thanks to compatible strings,
- documentation can be found in Documentation/devicetree/bindings,
- for a more in-depth explanation on what a Device Tree is and how to write it: https://www.youtube.com/watch?v=m_NyYEBxfn8,
Free Electrons - Embedded Linux, kernel, drivers - Development, consulting, training and support. http://free-electrons.com | 32/40

1. write a map of your IPs’ relationships,
2. find the SoC DTSI that you’ll include,
3. look for IPs’ drivers in the correct subsystem,
- greping the (code)name of the IP is usually a good start,
4. once found, look for the compatible string in Documentation/devicetree/bindings,
5. follow the documentation to add the correct binding,
6. some bindings are framework-wide defined so make sure to read the documentation of the framework involved,
7. for SoC IPs, correct binding is usually as simple as enabling them and setting the correct power supply and pinmuxing since most is already described in the SoC Device Tree,
Free Electrons - Embedded Linux, kernel, drivers - Development, consulting, training and support. http://free-electrons.com | 33/40

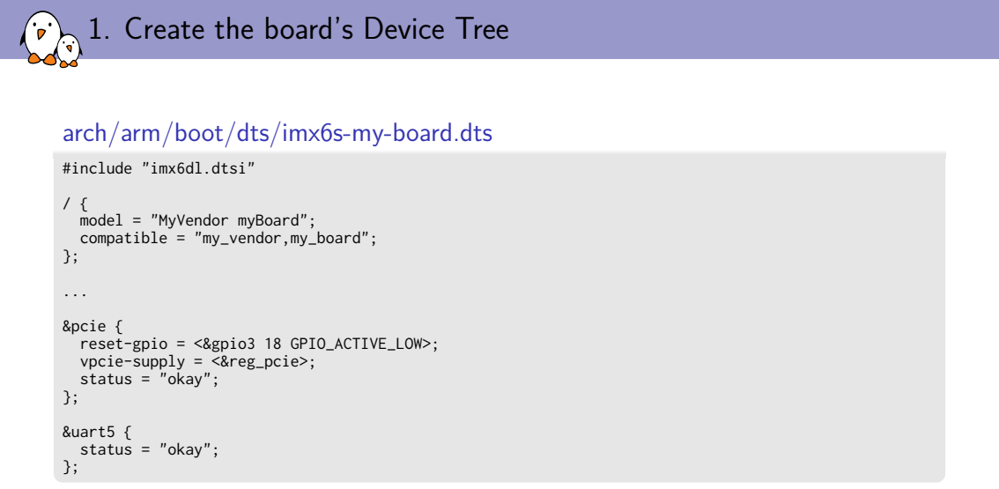
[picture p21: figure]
1. Create the board’s Device Tree; arch/arm/boot/dts/imx6s-my-board.dts; #include "imx6dl.dtsi"; / { model = "MyVendor myBoard"; compatible = "my_vendor,my_board";; &pcie { reset-gpio = <&gpio3 18 GPIO_ACTIVE_LOW>; vpcie-supply = <&reg_pcie>; status = "okay";; &uart5 { status = "okay";

Free Electrons - Embedded Linux, kernel, drivers - Development, consulting, training and support. http://free-electrons.com | 34/40

arch/arm/boot/dts/Makefile

dtb-$(CONFIG_MACH_KIRKWOOD) += \ #...

dtb-$(CONFIG_SOC_IMX6Q) += \ #...
imx6qp-sabresd.dtb \
imx6s-my-board.dtb
Free Electrons - Embedded Linux, kernel, drivers - Development, consulting, training and support. http://free-electrons.com | 35/40

1. start from the SoC family defconfig (e.g. imx_v6_v7_defconfig) or if there isn’t one, from the architecture (e.g. multi_v7_defconfig),
2. strip the defconfig of useless SoC families, drivers and features,
3. add the CONFIG of the drivers you want to compile,
- greping for the basename of the driver is the way to go,
- most drivers depend on subsystems or other options, you have to add them to your defconfig as well if your driver doesn’t select them,
Free Electrons - Embedded Linux, kernel, drivers - Development, consulting, training and support. http://free-electrons.com | 36/40

- PCIe driver was probing but not enumerating devices,
- driver was working in BSP, found out missing support for regulator was the culprit,
- quickly wrote a 40 lines patch and sent it upstream,
- Ethernet driver was missing a post reset delay for the PHY that was set in BSP,
- quickly wrote a 20 lines patch and sent it upstream,
Free Electrons - Embedded Linux, kernel, drivers - Development, consulting, training and support. http://free-electrons.com | 37/40

- Ethernet, I2C, SPI, NAND, eMMC, SD Card reader, USB device, EEPROM, GPIO, UART, audio (I2S), HDMI, LVDS, PCIe, USB host, RTC, PMIC,

$ wc -l arch/arm/boot/dts/imx6s-my-board.dts
arch/arm/configs/my_board_defconfig
606 arch/arm/boot/dts/imx6s-my-board.dts
401 arch/arm/configs/my_board_defconfig
1007 total
- +1 line in arch/arm/boot/dts/Makefile,
- +20 lines for regulator support in PCIe driver (now upstream),
- +40 lines for Ethernet PHY post reset delay (now upstream),
- no modification of Linux source code otherwise,
Free Electrons - Embedded Linux, kernel, drivers - Development, consulting, training and support. http://free-electrons.com | 38/40

- got some weird bug with dual display, the display driver would completely crash if both HDMI and LVDS outputs were enabled at the same time,
- update from 4.9 to 4.13 was very easy:
- copy DTB from 4.9 to 4.13 and make sure the bindings haven’t changed in-between those versions,
- add the one-liner in arch/arm/boot/dts/Makefile,
- patches were already upstream so nothing else to do,
- problem solved in ~30min by updating,
Free Electrons - Embedded Linux, kernel, drivers - Development, consulting, training and support. http://free-electrons.com | 39/40

# Questions?

# Quentin Schulz

quentin.schulz@free-electrons.com

Slides under CC-BY-SA 3.0
http://free-electrons.com/pub/conferences/2017/elce/schulz-how-to-support-new-board-u-boot-linux
Free Electrons - Embedded Linux, kernel, drivers - Development, consulting, training and support. http://free-electrons.com | 40/40

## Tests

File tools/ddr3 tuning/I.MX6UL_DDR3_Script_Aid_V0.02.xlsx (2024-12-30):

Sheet: Readme
NOTE
This tool only can be used for i.MX6UL with DDR3.
The DDR3/DDR3L interface mode fully complies with JESD79-3E DDR3 JEDEC standard release July,2010.
Freescale have right to change this tool without notice.
Performance and stability are executed in this tool, no power saving is traded off.
HOW TO USE
Fill all "Orange"+"Blue" cells in "Register Configuration" Page,then get advanced DDR script in "RealView .inc" Page.
Using "DDR Stress Test Tool" and generate Write Leveling, DQS Gating,Read and Write Delay Calibration result.
Please refer to "Red" cells in RealView.inc Tab on where these Calibration results must be updated into the final DDR initialization script.
If the result is different with yours, please try to understand the setting and make decision.
Please note that some settings only can impact efferency a little.
Please ask DDR device vendor or FSL supporter if any unclear point is existed.
Version
0.02 19-May-2016

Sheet: Register Configuration
Device Information
Manufacturer: | Micron
Memory part number: | MT41K256M16HA-125
Memory type: | DDR3-1600 | 1600 | Please note that all "Orange" and "Blue" Cells must be correct, they will impact the validity of register value and register address in Page "RealView .inc".
DRAM density (Gb) | 4
DRAM Bus Width | 16
Number of Banks | 8
Number of ROW Addresses | 15
Number of COLUMN Addresses | 10
Page Size (K) | 2
Self-Refresh Temperature (SRT) | Extended
tRCD=tRP=CL (ns) | 13.75
tRC Min (ns) | 48.75
tRAS Min (ns) | 35
System Information
i.Mx Part | i.MX6UL
Bus Width | 16
Density per chip select (Gb) | 4
Number of Chip Selects used | 1 | If only one CS is used, that must be CS0.
Total DRAM Density (Gb) | 4
DRAM Clock Freq (MHz) | 400
DRAM Clock Cycle Time (ns) | 2.5
Address Mirror (for CS1) | Disable
SI Configuration
DRAM DSE Setting - DQ/DQM (ohm) | 48
DRAM DSE Setting - ADDR/CMD/CTL (ohm) | 48
DRAM DSE Setting - CK (ohm) | 48
DRAM DSE Setting - DQS (ohm) | 48
System ODT Setting (ohm) | 60

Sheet: RealView .inc
//=============================================================================
//init script for i.MX6UL DDR3
//=============================================================================
// Revision History
// v01
//=============================================================================
wait = on
//=============================================================================
// Disable | WDOG
//=============================================================================
setmem /16 | 0x020bc000 = | 0x30
//=============================================================================
// Enable all clocks (they are disabled by ROM code)
//=============================================================================
setmem /32 | 0x020c4068 = | 0xffffffff
setmem /32 | 0x020c406c = | 0xffffffff
setmem /32 | 0x020c4070 = | 0xffffffff
setmem /32 | 0x020c4074 = | 0xffffffff
setmem /32 | 0x020c4078 = | 0xffffffff
setmem /32 | 0x020c407c = | 0xffffffff
setmem /32 | 0x020c4080 = | 0xffffffff
//=============================================================================
// IOMUX
//=============================================================================
//DDR IO TYPE:
setmem /32 | 0x020e04b4 = | 0x000C0000 | // IOMUXC_SW_PAD_CTL_GRP_DDR_TYPE
setmem /32 | 0x020e04ac = | 0x00000000 | // IOMUXC_SW_PAD_CTL_GRP_DDRPKE
//CLOCK:
setmem /32 | 0x020e027c = | 0x00000028 | // IOMUXC_SW_PAD_CTL_PAD_DRAM_SDCLK_0
//ADDRESS:
setmem /32 | 0x020e0250 = | 0x00000028 | // IOMUXC_SW_PAD_CTL_PAD_DRAM_CAS
setmem /32 | 0x020e024c = | 0x00000028 | // IOMUXC_SW_PAD_CTL_PAD_DRAM_RAS
setmem /32 | 0x020e0490 = | 0x00000028 | // IOMUXC_SW_PAD_CTL_GRP_ADDDS
//Control:
setmem /32 | 0x020e0288 = | 0x00000028 | // IOMUXC_SW_PAD_CTL_PAD_DRAM_RESET
setmem /32 | 0x020e0270 = | 0x00000000 | // IOMUXC_SW_PAD_CTL_PAD_DRAM_SDBA2 - DSE can be configured using Group Control Register: IOMUXC_SW_PAD_CTL_GRP_CTLDS
setmem /32 | 0x020e0260 = | 0x00000028 | // IOMUXC_SW_PAD_CTL_PAD_DRAM_SDODT0
setmem /32 | 0x020e0264 = | 0x00000028 | // IOMUXC_SW_PAD_CTL_PAD_DRAM_SDODT1
setmem /32 | 0x020e04a0 = | 0x00000028 | // IOMUXC_SW_PAD_CTL_GRP_CTLDS
//Data Strobes:
setmem /32 | 0x020e0494 = | 0x00020000 | // IOMUXC_SW_PAD_CTL_GRP_DDRMODE_CTL
setmem /32 | 0x020e0280 = | 0x00000028 | // IOMUXC_SW_PAD_CTL_PAD_DRAM_SDQS0
setmem /32 | 0x020e0284 = | 0x00000028 | // IOMUXC_SW_PAD_CTL_PAD_DRAM_SDQS1
//Data:
setmem /32 | 0x020e04b0 = | 0x00020000 | // IOMUXC_SW_PAD_CTL_GRP_DDRMODE
setmem /32 | 0x020e0498 = | 0x00000028 | // IOMUXC_SW_PAD_CTL_GRP_B0DS
setmem /32 | 0x020e04a4 = | 0x00000028 | // IOMUXC_SW_PAD_CTL_GRP_B1DS
setmem /32 | 0x020e0244 = | 0x00000028 | // IOMUXC_SW_PAD_CTL_PAD_DRAM_DQM0
setmem /32 | 0x020e0248 = | 0x00000028 | // IOMUXC_SW_PAD_CTL_PAD_DRAM_DQM1
//=============================================================================
// DDR Controller Registers
//=============================================================================
// Manufacturer: | Micron
// Device Part Number: | MT41K256M16HA-125
// Clock Freq.: | 400MHz
// Density per CS in Gb: | 4
// Chip Selects used: | 1
// Number of Banks: | 8
// Row address: | 15
// Column address: | 10
// Data bus width | 16
//=============================================================================
setmem /32 | 0x021b001c = | 0x00008000 | // MMDC0_MDSCR, set the Configuration request bit during MMDC set up
//=============================================================================
// Calibration setup.
//=============================================================================
setmem /32 | 0x021b0800 = | 0xA1390003 | // DDR_PHY_P0_MPZQHWCTRL, enable both one-time & periodic HW ZQ calibration.
// For target board, may need to run write leveling calibration to fine tune these settings.
setmem /32 | 0x021b080c = | 0x00000000
//Read DQS Gating calibration
setmem /32 | 0x021b083c = | 0x00000000 | // MPDGCTRL0 PHY0
//Read calibration
setmem /32 | 0x021b0848 = | 0x40404040 | // MPRDDLCTL PHY0
//Write calibration
setmem /32 | 0x021b0850 = | 0x40404040 | // MPWRDLCTL PHY0
//read data bit delay: (3 is the reccommended default value, although out of reset value is 0)
setmem /32 | 0x021b081c = | 0x33333333 | // MMDC_MPRDDQBY0DL
setmem /32 | 0x021b0820 = | 0x33333333 | // MMDC_MPRDDQBY1DL
//write data bit delay:
setmem /32 | 0x021b082c = | 0xF3333333 | // MMDC_MPWRDQBY0DL
setmem /32 | 0x021b0830 = | 0xF3333333 | // MMDC_MPWRDQBY1DL
//DQS&CLK Duty Cycle
setmem /32 | 0x021b08c0 = | 0x00921012 | // [MMDC_MPDCCR] MMDC Duty Cycle Control Register
// Complete calibration by forced measurement:
setmem /32 | 0x021b08b8 = | 0x00000800 | // DDR_PHY_P0_MPMUR0, frc_msr
//=============================================================================
// Calibration setup end
//=============================================================================
//MMDC init:
setmem /32 | 0x021b0004 = | 0x0002002D | // MMDC0_MDPDC
setmem /32 | 0x021b0008 = | 0x1B333030 | // MMDC0_MDOTC
setmem /32 | 0x021b000c = | 0x676B52F3 | // MMDC0_MDCFG0
setmem /32 | 0x021b0010 = | 0xB66D0B63 | // MMDC0_MDCFG1
setmem /32 | 0x021b0014 = | 0x01FF00DB | // MMDC0_MDCFG2
//MDMISC: RALAT kept to the high level of 5.
//MDMISC: consider reducing RALAT if your 528MHz board design allow that. Lower RALAT benefits:
//a. better operation at low frequency, for LPDDR2 freq < 100MHz, change RALAT to 3
//b. Small performence improvment
setmem /32 | 0x021b0018 = | 0x00211740 | // MMDC0_MDMISC
setmem /32 | 0x021b001c = | 0x00008000 | // MMDC0_MDSCR, set the Configuration request bit during MMDC set up
setmem /32 | 0x021b002c = | 0x000026D2 | // MMDC0_MDRWD
setmem /32 | 0x021b0030 = | 0x006B1023 | // MMDC0_MDOR
setmem /32 | 0x021b0040 = | 0x0000004F | // Chan0 CS0_END
setmem /32 | 0x021b0000 = | 0x84180000 | // MMDC0_MDCTL
setmem /32 | 0x021b0890 = | 0x00400a38 | // MPPDCMPR2
//Mode register writes
setmem /32 | 0x021b001c = | 0x02008032 | // MMDC0_MDSCR, MR2 write, CS0
setmem /32 | 0x021b001c = | 0x00008033 | // MMDC0_MDSCR, MR3 write, CS0
setmem /32 | 0x021b001c = | 0x00048031 | // MMDC0_MDSCR, MR1 write, CS0
setmem /32 | 0x021b001c = | 0x15208030 | // MMDC0_MDSCR, MR0write, CS0
setmem /32 | 0x021b001c = | 0x04008040 | // MMDC0_MDSCR, ZQ calibration command sent to device on CS0
//setmem /32 | 0x021b001c = | 0x0200803A | // MMDC0_MDSCR, MR2 write, CS1
//setmem /32 | 0x021b001c = | 0x0000803B | // MMDC0_MDSCR, MR3 write, CS1
//setmem /32 | 0x021b001c = | 0x00048039 | // MMDC0_MDSCR, MR1 write, CS1
//setmem /32 | 0x021b001c = | 0x15208038 | // MMDC0_MDSCR, MR0write, CS1
//setmem /32 | 0x021b001c = | 0x04008048 | // MMDC0_MDSCR, ZQ calibration command sent to device on CS1
setmem /32 | 0x021b0020 = | 0x00007800 | // MMDC0_MDREF
setmem /32 | 0x021b0818 = | 0x00000227 | // DDR_PHY_P0_MPODTCTRL
setmem /32 | 0x021b0004 = | 0x0002556D | // MMDC0_MDPDC now SDCTL power down enabled
setmem /32 | 0x021b0404 = | 0x00011006 | // MMDC0_MAPSR ADOPT power down enabled, MMDC will enter automatically to self-refresh while the number of idle cycle reached.
setmem /32 | 0x021b001c = | 0x00000000 | // MMDC0_MDSCR, clear this register (especially the configuration bit as initialization is complete)

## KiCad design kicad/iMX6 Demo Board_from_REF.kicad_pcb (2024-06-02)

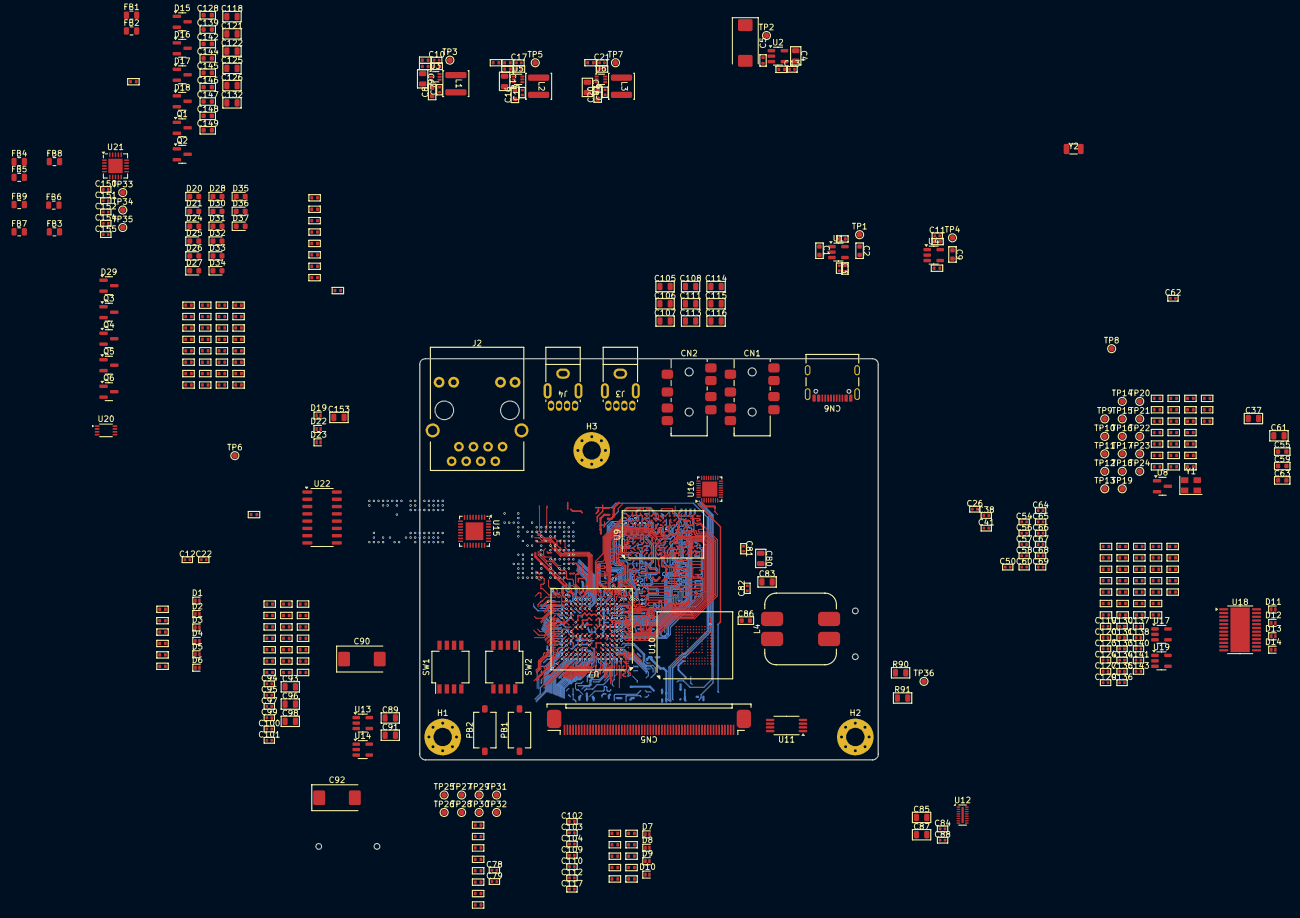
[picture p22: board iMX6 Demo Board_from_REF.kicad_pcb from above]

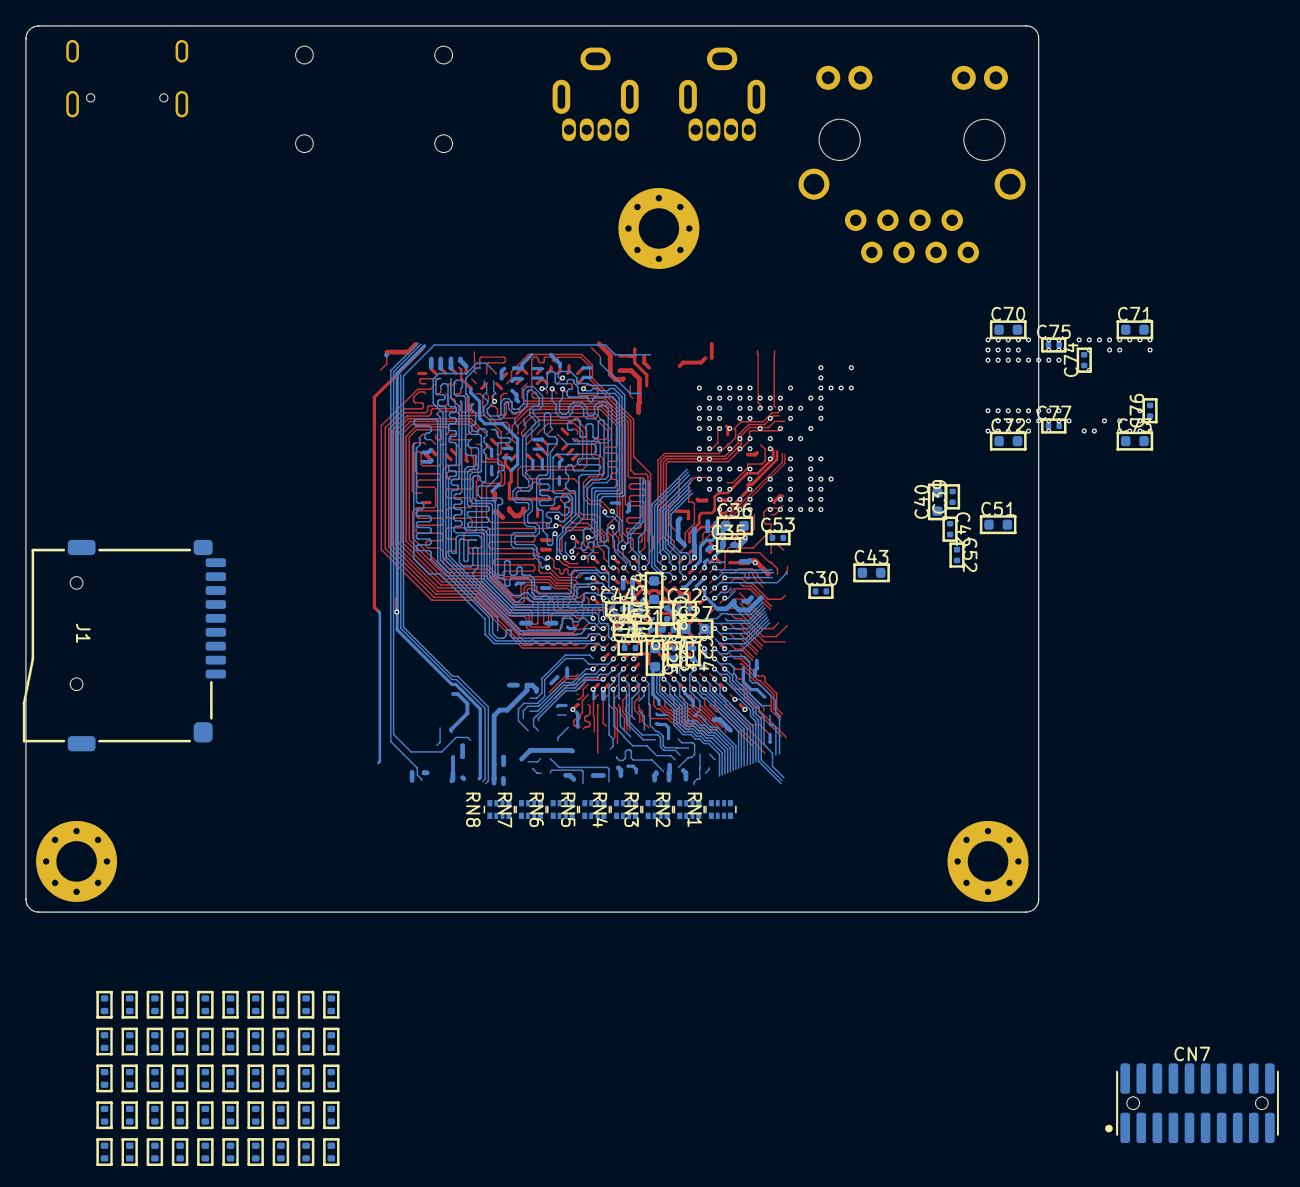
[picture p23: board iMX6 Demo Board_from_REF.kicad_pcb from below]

Board: 6 copper layers, 80.0 x 70.0 mm, 504 parts (91 on the bottom side), 405 nets.

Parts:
C1, C2, C8, C9, C16, C20, C55, C59, C63, C86, C128, C139, C142, C144, C145, C146, C147, C148, C149: 1 uF; CAP-0603
C3: 220 pF; CAP-0402
C4, C6, C14, C18, C80, C83, C85, C87, C89, C91, C98, C105, C106, C107, C108, C111, C113, C114, C115, C116, C118, C121, C122, C125, C126, C132, C153: 2.2 uF; CAP-0805
C5, C90, C92: 150 uF; CP_EIA-7343-31_Kemet-D
C7, C12, C13, C15, C19, C26, C50, C56, C57, C58, C60, C62, C64, C69, C78, C79, C81, C82, C84, C88, C94, C95, C97, C99, C100, C101, C102, C103, C104, C109, C110, C112, C117, C119, C120, C127, C130, C131, C133, C135, C140, C141, C143, C150, C151, C152, C154, C155: 100 nF; CAP-0402
C10, C17, C21, C65, C66, C67, C68, C123, C124, C129, C136: 22 pF; CAP-0402
C11: 560 pF; CAP-0402
C22, C134, C137, C138: 2.2 nF; CAP-0402
C23, C24, C28, C29, C30, C31, C32, C33, C35, C38, C39, C41, C42, C44, C45, C46, C52, C53, C54, C74, C75, C76, C77: 220 nF; CAP-0402
C25, C27, C34: 22 uF; CAP-0603
C36, C40, C43: 10 uF; CAP-0603
C37, C61, C93, C96: 22 uF; CAP-0805
C51, C70, C71, C72, C73: 2.2 uF; CAP-0603
CN1, CN2: PJ-393 8PJ; Jack_SMD_3.5mm_PJ-393-8PJ
CN5: KH-CL0.5-H2.0-60PS; CN-FPC-KH-CL0.5-H2.0-60PS
CN6: USB4105-GF-A; USB-TYPE-C-12P
CN7: 20021121-00020C4LF; CN-SMD-2x10P-1.27MM-FR
D1, D2, D3, D4, D5, D6, D7, D8, D9, D10, D11, D12, D13, D14, D19, D22, D23: LESD8D5.0CAT5G; D_SOD-882
D15, D16, D17, D18, D29: BAT54S; SOT-23
D20, D24: 150060RS75003; LED_0603_1608Metric
D21, D25, D26, D27, D28, D30, D31, D32, D33, D34, D35, D36, D37: 150060VS75000; LED_0603_1608Metric
FB1, FB2, FB3, FB4, FB5, FB6, FB7, FB8, FB9: GZ2012D101TF; FB-0805
H1, H2, H3: MountingHole_Pad; MountingHole_3.2mm_M3_Pad_Via
J1: GT-TF003-H0185-01; MicroSD_G-Switch _GT-TF003-H0185-01
J2: HR911105A; RJ45_THT-HR911105A
J3, J4: 906-762B1026D10200; USB-TypeA-906-762B1026D10200
L1, L2, L3: 27 uH; IND-SMD-FNR4020S
L4: 6.8 uH; IND-SMD-ACPR1208S
PB1, PB2: PTS636 SK25 SMTR LFS; BTN_SMD_PTS636-SK25-SMTR-LFS
Q1: NTR5105PT1G; SOT-23
Q2, Q3, Q4, Q5, Q6: SMMBT3904LT1G; SOT-23
R1: 56.2K; RES-0402
R2, R6, R8, R9, R10: 18K; RES-0402
R3, R5, R11, R12, R15, R116: 82K; RES-0402
R4: 24K; RES-0402
R7, R18, R19, R20, R23, R24, R29, R43, R44, R45, R49, R50, R51, R52, R53, R54, R55, R56, R57, R58, R61, R66, R67, R68, R72, R73, R74, R78, R79, R84, R86, R89, R92, R93, R94, R97, R98, R131, R132, R133, R134, R135, R136, R137, R138, R139, R140, R141, R142, R143, R144, R145, R146, R147, R148, R149, R150, R155, R156, R157, R158, R159, R160, R161, R162, R163, R164, R165, R166, R167, R168, R169, R170, R171, R172, R173, R174, R175, R176, R177, R178, R179, R180, R197, R198, R199, R200, R201, R202, R211, R212: 10K; RES-0402
R13: 72K; RES-0402
R14: 820R; RES-0402
R16: 64.9K; RES-0402
R17, R41, R42: 240R; RES-0402
R21, R25, R26, R104, R105, R107, R108, R109, R117, R119, R120, R123, R126: 0R; RES-0402
R22, R46, R47, R59, R60, R62, R69, R70, R71, R75, R76, R77, R80, R81, R82, R83, R85, R111, R112, R151, R152, R153, R154, R187, R188: 1.5K; RES-0402
R27, R28, R30, R31, R32, R33, R34, R35, R36, R37, R40: 1M; RES-0402
R38, R87, R88, R95, R96, R181, R182, R183, R184, R185, R186: 22R; RES-0402
R39, R63, R64, R99, R100, R101, R106, R191, R192, R193, R194, R195, R196, R203, R204, R205, R206, R207, R208, R209, R210: 220R; RES-0402
R48: 470R; RES-0402
R65: 6.49K; RES-0402
R90, R91: 100K; RES-0805
R102, R115: 62K; RES-0402
R103, R113, R114, R118: 680K; RES-0402
R110, R121, R122, R124, R125, R127, R128, R129, R130: 47K; RES-0402
R189, R190: 5.1K; RES-0402
RN1, RN2, RN3, RN4, RN5, RN6, RN7, RN8: 4x22R; R_Array_Convex_4x0402
SW1, SW2: EP-04KS; SW_DIP_SPSTx04_Slide_Copal_CHS-04B_W7.62mm_P1.27mm
TP1, TP2, TP3, TP4, TP5, TP6, TP7, TP8, TP9, TP10, TP11, TP12, TP13, TP14, TP15, TP16, TP17, TP18, TP19, TP20, TP21, TP22, TP23, TP24, TP25, TP26, TP27, TP28, TP29, TP30, TP31, TP32, TP33, TP34, TP35, TP36: TestPoint_Pad_D1.0mm
U1, U4: AP2127K-ADJTRG1; SOT-23-5
U2, U13, U14, U17: MT9700; SOT-23-5
U3, U5, U6: SY8892ARC; SOT-563
U7: MCIMX6Y2CVM08AB; BGA-289P08L17x17_14.0x14.0mm_Ball0.35mm_Pad0.30mm
U8: UM803RS; SOT-23
U9: MT41K256M16TW-107; BGA-96P08L9X16_8.0X14.0mm_Ball0.45_Pad0.40mm
U10: THGBMNG5D1LBAIL; BGA-153_13.0x11.5mm_Ball0.30mm_Pad0.25mm
U11: ZD25WQ80BOIGT; TSSOP-8_4.4x3mm_P0.65mm
U12: IP4252CZ16-8-TTL; Nexperia_HUSON-16_USON-16-1EP_1.35x3.3mm_P0.4mm_EP0.4x2.8mm
U15: KSZ8081RNBIA-TR; QFN-32-1EP_5x5mm_P0.5mm_EP3.1x3.1mm
U16: WM8904CGEFL/RV; QFN-32-1EP_4x4mm_P0.4mm_EP2.65x2.65mm
U18: TPS65150PWPR; HTSSOP-24-1EP_4.4x7.8mm_P0.65mm_EP3.4x7.8mm_Mask2.4x4.68mm
U19: LMV321IDBVR; SOT-23-5
U20: TXS0102DCUR; VSSOP-8_2.3x2mm_P0.5mm
U21: FT231XQ; QFN-20-1EP_4x4mm_P0.5mm_EP2.5x2.5mm
U22: 74HC595D,118; SO-16_3.9x9.9mm_P1.27mm
Y1: 24 MHz; Crystal_SMD_EuroQuartz_MT-4Pin_3.2x2.5mm
Y2: 32.768 KHz; QUARTZ-SC-32S32.768kHz20PPM12.5pF

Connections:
+1.8V: C9.1, C11.2, C26.1, C56.1, C80.1, C81.1, C84.1, C85.1, C102.2, C103.2, C107.1, C108.1, C109.2, FB7.1, R4.2, R49.1, R92.1, R93.1, TP4.1, U4.5 (VOUT), U7.E7 (NVCC_NAND), U7.F4 (NVCC_CSI), U10.C6 (VCCQ), U10.M4 (VCCQ), U10.N4 (VCCQ), U10.P3 (VCCQ), U10.P5 (VCCQ), U11.8 (VCC), U16.4 (DBVDD), U16.6 (DCVDD), U16.7 (CPVDD), U16.19 (MICVDD)
+3V3_DCDC: C7.1, C8.1, C10.2, C50.1, C62.1, C63.1, C64.1, C69.1, C82.1, C83.1, C93.1, C94.2, C152.1, CN7.2, FB1.1, FB2.1, FB3.1, FB6.2, J2.9 (GA), J2.12 (YA), L1.2, R5.2, R23.1, R24.1, R50.2, R51.2, R52.2, R53.2, R54.2, R55.2, R56.2, R59.1, R60.1, R61.1, R62.1, R66.2, R67.2, R68.2, R72.2, R73.2, R74.2, R78.2, R79.2, R84.2, R119.1, R131.1, R132.1, R133.1, R134.1, R135.1, R136.1, R137.1, R138.1, R139.1, R140.1, R141.1, R142.1, R143.1, R144.1, R145.1, R146.1, R147.1, R148.1, R149.1, R150.1, R151.1, R152.1, R153.1, R154.1, R155.1, R156.1, R191.1, R192.1, R193.1, R194.1, R195.1, R196.1, R203.1, R204.1, R205.1, R206.1, R207.1, R208.1, R209.1, R210.1, R211.1, TP3.1, U4.1 (VDD), U7.C4 (NVCC_SD1), U7.E13 (NVCC_LCD), U7.F13 (NVCC_ENET), U7.H13 (NVCC_UART), U7.J13 (NVCC_GPIO), U8.3 (VCC), U10.E6 (VCC), U10.F5 (VCC), U10.J10 (VCC), U10.K9 (VCC), U15.17 (VDDIO), U20.3 (VCCA), U22.16 (VCC)
+3V3_FTDI: C150.1, C151.1, C155.2, R187.2, R188.2, U20.7 (VCCB), U21.10 (3V3OUT), U21.11 (~REST), U21.20 (VCCIO)
+3V3_STAND_BY: C2.1, C3.2, C41.1, R1.2, TP1.1, U1.5 (VOUT), U7.P12 (VDD_SNVS_IN)
+5V_LCD: C119.1, C140.1, FB8.1, R124.2, R125.2, U17.1 (VOUT)
+5V_VBUS: C1.1, C4.1, C89.1, C91.1, C118.1, CN6.2 (VBUS), CN6.11 (VBUS), D19.2 (A2), FB9.1, U1.1 (VDD), U1.3 (EN), U2.5 (VIN), U13.5 (VIN), U14.5 (VIN), U17.5 (VIN)
+5V_VBUS_USB1: C55.1, C90.1, FB4.1, U7.T12 (USB_OTG1_VBUS), U13.1 (VOUT)
+5V_VBUS_USB2: C59.1, C92.1, FB5.1, U7.U12 (USB_OTG2_VBUS), U14.1 (VOUT)
+VDD_DRAM: C19.1, C20.1, C21.2, C43.1, C44.1, C45.1, C46.1, C70.1, C71.1, C72.1, C73.1, C74.1, C75.1, C76.1, C77.1, C78.1, L3.2, R15.2, R46.1, TP7.1, U7.G6 (NVCC_DRAM), U7.H6 (NVCC_DRAM), U7.J6 (NVCC_DRAM), U7.K6 (NVCC_DRAM), U7.L6 (NVCC_DRAM), U7.M6 (NVCC_DRAM), U9.A1 (VDDQ), U9.A8 (VDDQ), U9.B2 (VDD), U9.C1 (VDDQ), U9.C9 (VDDQ), U9.D2 (VDDQ), U9.D9 (VDD), U9.E9 (VDDQ), U9.F1 (VDDQ), U9.G7 (VDD), U9.H2 (VDDQ), U9.H9 (VDDQ), U9.K2 (VDD), U9.K8 (VDD), U9.N1 (VDD), U9.N9 (VDD), U9.R1 (VDD), U9.R9 (VDD)
+VDD_HIGH_CAP: C35.1, C36.1, C53.1, TP10.1, U7.N6 (NVCC_DRAM_2P5), U7.R14 (VDD_HIGH_CAP), U7.R15 (VDD_HIGH_CAP)
+VDD_SOC: C15.1, C16.1, C17.2, C27.1, C28.1, C29.1, C30.1, L2.2, R12.2, TP5.1, U7.H9 (VDD_SOC_IN), U7.H10 (VDD_SOC_IN), U7.J9 (VDD_SOC_IN), U7.J10 (VDD_SOC_IN), U7.K9 (VDD_SOC_IN), U7.K10 (VDD_SOC_IN)
/i.MX6ULL MAIN/AUDIO CODEC/I2C1.SCL: R92.2, U7.E5 (CSI_PIXCLK), U16.2 (SCLK)
/i.MX6ULL MAIN/AUDIO CODEC/I2C1.SDA: R93.2, U7.F5 (CSI_MCLK), U16.3 (SDA)
/i.MX6ULL MAIN/AUDIO CODEC/I2S_ADCDAT: U7.D2 (CSI_DATA06), U16.31 (ADCDAT)
/i.MX6ULL MAIN/AUDIO CODEC/I2S_BCLK: U7.D3 (CSI_DATA05), U16.29 (BCLK_/_GPIO4)
/i.MX6ULL MAIN/AUDIO CODEC/I2S_DACDAT: U7.D1 (CSI_DATA07), U16.32 (DACDAT)
/i.MX6ULL MAIN/AUDIO CODEC/I2S_LRCLK: U7.D4 (CSI_DATA04), U16.30 (LRCLK)
/i.MX6ULL MAIN/AUDIO CODEC/I2S_MCLK: U7.E3 (CSI_DATA01), U16.28 (MCLK)
/i.MX6ULL MAIN/BOOT CONFIG/BOOT_MODE_0: SW2.2, U7.T10 (BOOT_MODE0)
/i.MX6ULL MAIN/BOOT CONFIG/BOOT_MODE_1: SW2.1, U7.U10 (BOOT_MODE1)
/i.MX6ULL MAIN/BOOT CONFIG/LCD_DATA0: R157.1, RN2.6 (R3.2), SW1.4, U7.B9 (LCD_DATA00)
/i.MX6ULL MAIN/BOOT CONFIG/LCD_DATA1: R150.2, R158.1, RN2.7 (R2.2), U7.A9 (LCD_DATA01)
/i.MX6ULL MAIN/BOOT CONFIG/LCD_DATA2: R149.2, R159.1, RN2.8 (R1.2), U7.E10 (LCD_DATA02)
/i.MX6ULL MAIN/BOOT CONFIG/LCD_DATA3: R148.2, R160.1, RN3.5 (R4.2), U7.D10 (LCD_DATA03)
/i.MX6ULL MAIN/BOOT CONFIG/LCD_DATA4: R147.2, R161.1, RN3.6 (R3.2), U7.C10 (LCD_DATA04)
/i.MX6ULL MAIN/BOOT CONFIG/LCD_DATA5: R162.1, RN3.7 (R2.2), SW1.3, U7.B10 (LCD_DATA05)
/i.MX6ULL MAIN/BOOT CONFIG/LCD_DATA6: R163.1, RN3.8 (R1.2), SW1.2, U7.A10 (LCD_DATA06)
/i.MX6ULL MAIN/BOOT CONFIG/LCD_DATA7: R164.1, RN4.5 (R4.2), SW1.1, U7.D11 (LCD_DATA07)
/i.MX6ULL MAIN/BOOT CONFIG/LCD_DATA8: R146.2, R165.1, RN4.6 (R3.2), U7.B11 (LCD_DATA08)
/i.MX6ULL MAIN/BOOT CONFIG/LCD_DATA9: R145.2, R166.1, RN4.7 (R2.2), U7.A11 (LCD_DATA09)
/i.MX6ULL MAIN/BOOT CONFIG/LCD_DATA10: R144.2, R167.1, RN4.8 (R1.2), U7.E12 (LCD_DATA10)
/i.MX6ULL MAIN/BOOT CONFIG/LCD_DATA11: R143.2, R168.1, RN5.5 (R4.2), U7.D12 (LCD_DATA11)
/i.MX6ULL MAIN/BOOT CONFIG/LCD_DATA12: R142.2, R169.1, RN5.6 (R3.2), U7.C12 (LCD_DATA12)
/i.MX6ULL MAIN/BOOT CONFIG/LCD_DATA13: R141.2, R170.1, RN5.7 (R2.2), U7.B12 (LCD_DATA13)
/i.MX6ULL MAIN/BOOT CONFIG/LCD_DATA14: R140.2, R171.1, RN5.8 (R1.2), U7.A12 (LCD_DATA14)
/i.MX6ULL MAIN/BOOT CONFIG/LCD_DATA15: R139.2, R172.1, RN6.5 (R4.2), U7.D13 (LCD_DATA15)
/i.MX6ULL MAIN/BOOT CONFIG/LCD_DATA16: R138.2, R173.1, RN6.6 (R3.2), U7.C13 (LCD_DATA16)
/i.MX6ULL MAIN/BOOT CONFIG/LCD_DATA17: R137.2, R174.1, RN6.7 (R2.2), U7.B13 (LCD_DATA17)
/i.MX6ULL MAIN/BOOT CONFIG/LCD_DATA18: R136.2, R175.1, RN6.8 (R1.2), U7.A13 (LCD_DATA18)
/i.MX6ULL MAIN/BOOT CONFIG/LCD_DATA19: R135.2, R176.1, RN7.5 (R4.2), U7.D14 (LCD_DATA19)
/i.MX6ULL MAIN/BOOT CONFIG/LCD_DATA20: R134.2, R177.1, RN7.6 (R3.2), U7.C14 (LCD_DATA20)
/i.MX6ULL MAIN/BOOT CONFIG/LCD_DATA21: R133.2, R178.1, RN7.7 (R2.2), U7.B14 (LCD_DATA21)
/i.MX6ULL MAIN/BOOT CONFIG/LCD_DATA22: R132.2, R179.1, RN7.8 (R1.2), U7.A14 (LCD_DATA22)
/i.MX6ULL MAIN/BOOT CONFIG/LCD_DATA23: R131.2, R180.1, RN8.5 (R4.2), U7.B16 (LCD_DATA23)
/i.MX6ULL MAIN/BOOT CONFIG/LCD_DOTCLK: CN5.44, RN8.1 (R1.1), RN8.8 (R1.2), U7.A8 (LCD_CLK)
/i.MX6ULL MAIN/BOOT CONFIG/LCD_HSYNC: CN5.42, RN8.3 (R3.1), RN8.6 (R3.2), U7.D9 (LCD_HSYNC)
/i.MX6ULL MAIN/BOOT CONFIG/LCD_RESET: CN5.14, RN1.3 (R3.1), RN1.6 (R3.2), U7.E9 (LCD_RESET)
/i.MX6ULL MAIN/BOOT CONFIG/LCD_VSYNC: CN5.43, RN8.2 (R2.1), RN8.7 (R2.2), U7.C9 (LCD_VSYNC)
/i.MX6ULL MAIN/CONTROL GPIO/FTDI_RX: D21.1 (K), R183.1, TP34.1, U21.1 (RXD)
/i.MX6ULL MAIN/CONTROL GPIO/FTDI_TX: D20.1 (K), R181.1, TP33.1, U21.17 (TXD)
/i.MX6ULL MAIN/CONTROL GPIO/JTAG_DACK: CN7.19, R201.1
/i.MX6ULL MAIN/CONTROL GPIO/JTAG_RTCK: CN7.11, R202.1
/i.MX6ULL MAIN/CONTROL GPIO/JTAG_TCK: CN7.9, U7.M14 (JTAG_TCK)
/i.MX6ULL MAIN/CONTROL GPIO/JTAG_TDI: CN7.5, U7.N16 (JTAG_TDI)
/i.MX6ULL MAIN/CONTROL GPIO/JTAG_TDO: CN7.13, U7.N15 (JTAG_TDO)
/i.MX6ULL MAIN/CONTROL GPIO/JTAG_TMS: CN7.7, U7.P14 (JTAG_TMS)
/i.MX6ULL MAIN/CONTROL GPIO/JTAG_VREF: CN7.1, R196.2
/i.MX6ULL MAIN/CONTROL GPIO/LED_ACTIVITY: R197.2, U7.G14 (~UART3_RTS)
/i.MX6ULL MAIN/CONTROL GPIO/LED_EMMC: R198.2, U7.H16 (UART3_RX_DATA)
/i.MX6ULL MAIN/CONTROL GPIO/LED_NETWORK: R200.2, U7.J15 (~UART2_CTS)
/i.MX6ULL MAIN/CONTROL GPIO/LED_SD: R199.2, U7.H17 (UART3_TX_DATA)
/i.MX6ULL MAIN/CONTROL GPIO/LED_SR_RCLK: U7.G17 (UART4_TX_DATA), U22.12 (RCLK)
/i.MX6ULL MAIN/CONTROL GPIO/LED_SR_SER: U7.G13 (UART5_RX_DATA), U22.14 (SER)
/i.MX6ULL MAIN/CONTROL GPIO/LED_SR_SRCLK: U7.F17 (UART5_TX_DATA), U22.11 (SRCLK)
/i.MX6ULL MAIN/CONTROL GPIO/PMIC_POWER_GOOD: R11.2, R21.2, TP6.1, U5.6 (PG), U6.6 (PG), U13.4 (EN), U14.4 (EN), U17.4 (EN), U20.6 (OE)
/i.MX6ULL MAIN/CONTROL GPIO/UART1.RX: R182.2, U7.K16 (UART1_RX_DATA)
/i.MX6ULL MAIN/CONTROL GPIO/UART1.TX: R184.2, U7.K14 (UART1_TX_DATA)
/i.MX6ULL MAIN/CONTROL GPIO/USBD_n: CN6.5 (DN2), CN6.7 (DN1), D22.2 (A2), R186.1
/i.MX6ULL MAIN/CONTROL GPIO/USBD_p: CN6.6 (DP1), CN6.8 (DP2), D23.2 (A2), R185.1
/i.MX6ULL MAIN/CONTROL GPIO/~JTAG_SRST: CN7.15, D29.3 (common)
/i.MX6ULL MAIN/CONTROL GPIO/~JTAG_TRST: CN7.3, U7.N14 (JTAG_TRST_B)
/i.MX6ULL MAIN/CONTROL GPIO/~LED_SR_SRCLR: U7.G16 (UART4_RX_DATA), U22.10 (~SRCLR)
/i.MX6ULL MAIN/CPU/DRAM_A0: TP28.1, U7.L5 (DRAM_ADDR00), U9.N3 (A0)
/i.MX6ULL MAIN/CPU/DRAM_A1: U7.H2 (DRAM_ADDR01), U9.P7 (A1)
/i.MX6ULL MAIN/CPU/DRAM_A2: U7.K1 (DRAM_ADDR02), U9.P3 (A2)
/i.MX6ULL MAIN/CPU/DRAM_A3: U7.M2 (DRAM_ADDR03), U9.N2 (A3)
/i.MX6ULL MAIN/CPU/DRAM_A4: U7.K4 (DRAM_ADDR04), U9.P8 (A4)
/i.MX6ULL MAIN/CPU/DRAM_A5: U7.L1 (DRAM_ADDR05), U9.P2 (A5)
/i.MX6ULL MAIN/CPU/DRAM_A6: U7.G2 (DRAM_ADDR06), U9.R8 (A6)
/i.MX6ULL MAIN/CPU/DRAM_A7: U7.H4 (DRAM_ADDR07), U9.R2 (A7)
/i.MX6ULL MAIN/CPU/DRAM_A8: U7.J4 (DRAM_ADDR08), U9.T8 (A8)
/i.MX6ULL MAIN/CPU/DRAM_A9: U7.L2 (DRAM_ADDR09), U9.R3 (A9)
/i.MX6ULL MAIN/CPU/DRAM_A10: U7.M4 (DRAM_ADDR10), U9.L7 (A10/AP)
/i.MX6ULL MAIN/CPU/DRAM_A11: U7.K3 (DRAM_ADDR11), U9.R7 (A11)
/i.MX6ULL MAIN/CPU/DRAM_A12: U7.L4 (DRAM_ADDR12), U9.N7 (A12/~BC)
/i.MX6ULL MAIN/CPU/DRAM_A13: U7.H3 (DRAM_ADDR13), U9.T3 (A13)
/i.MX6ULL MAIN/CPU/DRAM_A14: U7.G1 (DRAM_ADDR14), U9.T7 (A14)
/i.MX6ULL MAIN/CPU/DRAM_A15: U7.K5 (DRAM_ADDR15), U9.M7 (NC_(A15))
/i.MX6ULL MAIN/CPU/DRAM_BA0: U7.M1 (DRAM_SDBA0), U9.M2 (BA0)
/i.MX6ULL MAIN/CPU/DRAM_BA1: U7.H1 (DRAM_SDBA1), U9.N8 (BA1)
/i.MX6ULL MAIN/CPU/DRAM_BA2: U7.K2 (DRAM_SDBA2), U9.M3 (BA2)
/i.MX6ULL MAIN/CPU/DRAM_CLK_EN0: R19.1, R45.1, U7.M3 (DRAM_SDCKE0), U9.K9 (CKE0)
/i.MX6ULL MAIN/CPU/DRAM_CLK_EN1: R20.1, R44.1, U7.J3 (DRAM_SDCKE1), U9.J9 (NC_(CKE1))
/i.MX6ULL MAIN/CPU/DRAM_CLK_N: R48.2, TP32.1, U7.P2 (DRAM_SDCLK0_N), U9.K7 (~CK)
/i.MX6ULL MAIN/CPU/DRAM_CLK_P: R48.1, TP26.1, U7.P1 (DRAM_SDCLK0_P), U9.J7 (CK)
/i.MX6ULL MAIN/CPU/DRAM_ODT0: U7.N1 (DRAM_ODT0), U9.K1 (ODT0)
/i.MX6ULL MAIN/CPU/DRAM_ODT1: U7.F1 (DRAM_ODT1), U9.J1 (NC_(ODT1))
/i.MX6ULL MAIN/CPU/ENET_CLK: R38.2, U15.9 (XI)
/i.MX6ULL MAIN/CPU/LCD_BACK_LIGHT: R112.1, U7.H15 (~UART3_CTS)
/i.MX6ULL MAIN/CPU/LCD_SPI_MOSI: RN2.5 (R4.2), U7.B15 (ENET2_TX_EN)
/i.MX6ULL MAIN/CPU/LCD_SPI_SCLK: RN1.8 (R1.2), U7.A16 (ENET2_TX_DATA1)
/i.MX6ULL MAIN/CPU/NVCC_PLL: C39.1, C40.1, TP11.1, U7.P13 (NVCC_PLL)
/i.MX6ULL MAIN/CPU/ONOFF: C57.1, PB1.2, R23.2, U7.R8 (ONOFF)
/i.MX6ULL MAIN/CPU/PMIC_ON_REQ: R10.1, U7.T9 (SNVS_PMIC_ON_REQ)
/i.MX6ULL MAIN/CPU/QSPI_DATA0: U7.A3 (~NAND_READY), U11.5 (SI/DQ0)
/i.MX6ULL MAIN/CPU/QSPI_DATA1: U7.C5 (~NAND_CE0), U11.2 (SO/DQ1)
/i.MX6ULL MAIN/CPU/QSPI_DATA2: U7.B5 (~NAND_CE1), U11.3 (~WP/DQ2)
/i.MX6ULL MAIN/CPU/QSPI_DATA3: U7.A4 (NAND_CLE), U11.7 (~HOLD/DQ3)
/i.MX6ULL MAIN/CPU/QSPI_SCLK: U7.D5 (~NAND_WP), U11.6 (SCLK)
/i.MX6ULL MAIN/CPU/RMII_CRS_DV/CONFIG2: R74.1, R77.1, U7.E16 (ENET1_RX_EN), U15.18 (CRS_DV/CONFIG2)
/i.MX6ULL MAIN/CPU/RMII_MDC: R59.2, U7.C16 (ENET2_RX_DATA1), U15.12 (MDC)
/i.MX6ULL MAIN/CPU/RMII_MDIO: R60.2, U7.C17 (ENET2_RX_DATA0), U15.11 (MDIO)
/i.MX6ULL MAIN/CPU/RMII_RXD0/DUPLEX: R83.1, U7.F16 (ENET1_RX_DATA0), U15.16 (RXD0/DUPLEX)
/i.MX6ULL MAIN/CPU/RMII_RXD1/PHYAD2: R68.1, R71.1, U7.E17 (ENET1_RX_DATA1), U15.15 (RXD1/PHYAD2)
/i.MX6ULL MAIN/CPU/RMII_RXER/ISO: R78.1, R80.1, U7.D15 (ENET1_RX_ER), U15.20 (RXER/ISO)
/i.MX6ULL MAIN/CPU/RMII_TXD0: U7.E15 (ENET1_TX_DATA0), U15.24 (TXD0)
/i.MX6ULL MAIN/CPU/RMII_TXD1: U7.E14 (ENET1_TX_DATA1), U15.25 (TXD1)
/i.MX6ULL MAIN/CPU/RMII_TXEN: U7.F15 (ENET1_TX_EN), U15.23 (TXEN)
/i.MX6ULL MAIN/CPU/SD_CARD_CMD: R54.1, U7.C2 (SD1_CMD), U12.3 (CH3)
/i.MX6ULL MAIN/CPU/SD_CARD_DATA0: R52.1, U7.B3 (SD1_DATA0), U12.5 (CH5)
/i.MX6ULL MAIN/CPU/SD_CARD_DATA1: R51.1, U7.B2 (SD1_DATA1), U12.6 (CH6)
/i.MX6ULL MAIN/CPU/SD_CARD_DATA2: R56.1, U7.B1 (SD1_DATA2), U12.1 (CH1)
/i.MX6ULL MAIN/CPU/SD_CARD_DATA3: R55.1, U7.A2 (SD1_DATA3), U12.2 (CH2)
/i.MX6ULL MAIN/CPU/SD_CARD_SCLK: R53.1, U7.C1 (SD1_CLK), U12.4 (CH4)
/i.MX6ULL MAIN/CPU/TOUCH.X1: D14.2 (A2), R104.1, U7.L17 (GPIO1_IO03)
/i.MX6ULL MAIN/CPU/TOUCH.X2: D12.2 (A2), R107.1, U7.M16 (GPIO1_IO04)
/i.MX6ULL MAIN/CPU/TOUCH.Y1: D13.2 (A2), R105.1, U7.L15 (GPIO1_IO01)
/i.MX6ULL MAIN/CPU/TOUCH.Y2: D11.2 (A2), R108.1, U7.L14 (GPIO1_IO02)
/i.MX6ULL MAIN/CPU/USB1.DN: D3.2 (A2), J3.3 (D+), U7.T15 (USB_OTG1_DN)
/i.MX6ULL MAIN/CPU/USB1.DP: D2.2 (A2), J3.2 (D-), U7.U15 (USB_OTG1_DP)
/i.MX6ULL MAIN/CPU/USB2.DN: D6.2 (A2), J4.3 (D+), U7.T13 (USB_OTG2_DN)
/i.MX6ULL MAIN/CPU/USB2.DP: D5.2 (A2), J4.2 (D-), U7.U13 (USB_OTG2_DP)
/i.MX6ULL MAIN/CPU/VDD_ARM_CAP: C23.1, C24.1, C25.1, TP8.1, U7.G9 (VDD_ARM_CAP), U7.G10 (VDD_ARM_CAP), U7.G11 (VDD_ARM_CAP), U7.H11 (VDD_ARM_CAP)
/i.MX6ULL MAIN/CPU/VDD_SNVS_CAP: C42.1, TP12.1, U7.N12 (VDD_SNVS_CAP)
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

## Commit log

2024-06-02 Add PCB Rev 00
    [AUDIO CODEC.kicad_sch, BOOT CONFIG.kicad_sch, CONTROL GPIO.kicad_sch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]
2024-11-27 Change schematic and PCB
    changed component U11 from 8MBit to 32 MBit
    added qr-code on bottom overlay
    [POWER TREE.kicad_sch, POWER.kicad_sch, USB.kicad_sch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]
2024-12-30 Add u-boot submodule
    [I.MX6UL_DDR3_Script_Aid_V0.02.xlsx]
2026-02-16 Fix hardware bugs - Fix part number in bom for resistors R103, R113, R114, R118 -> 680K - Fix part number in BOM for resistors R13, R16 -> 68K - Fix part number in BOM for resistor R14 -> 4.7K - Fix 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
    [AUDIO CODEC.kicad_sch, BOOT CONFIG.kicad_sch, CONTROL GPIO.kicad_sch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]
2026-02-16 Fix interactive BOM link
